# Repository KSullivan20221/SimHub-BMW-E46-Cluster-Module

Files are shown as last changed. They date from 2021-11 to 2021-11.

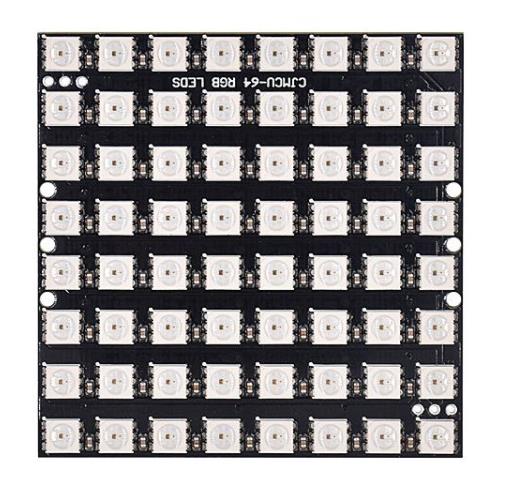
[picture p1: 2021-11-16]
Arduino Code/main-simhub-code/GroupPictures/WS2812B Matrix.jpg

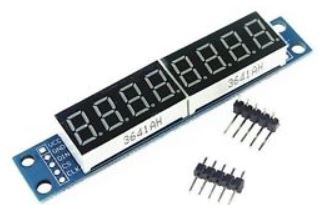
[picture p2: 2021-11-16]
Arduino Code/main-simhub-code/GroupPictures/MAX7221 7 Segments Modules.jpg

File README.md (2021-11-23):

# SimHub-BMW-E46-Cluster-Module
This repo contains all of the circuitry, code, and resources used to create a shield board for an Arduino Mega that could be used to communicate with a BWM E46 instrument cluster from a PC. The main application of this project was in using the cluster in conjunction with SimHub in order to show the values from the supported video games on the cluster's gauges. 

All of the testing I performed was on an E46 cluster with the following ID number and firmware:  
* Cluster Serial Number: 1031098105  
* Cluster Hardware Number: 30  (Can retrieve this by running the on-board 'Test 1' on the cluster, in test 1.5)  
* Cluster Software Number: 360 (Can retrieve this by running the on-board 'Test 1' on the cluster, in test 1.5)  

See the following link for how to retreive this data: https://www.e46fanatics.com/threads/just-found-us-version-of-hidden-menu.239619/

## Credits

There is no way I could have accomplished this project without many of the resources available to me:
* I never would have got off the ground if it weren't for this pinout diagram for the cluster: https://www.bmwgm5.com/E46_IKE_Connections.htm
* I borrowed several functions / hardware connections from _Neuros-Projekte_, as well as most all of the KBUS communication methods: https://neuros-projekte.de/simulator/bmw-e46-arduino-simhub/
* Most all of the CAN communication was from the extensive research done by the users on this bimmerforums forum: https://www.bimmerforums.com/forum/showthread.php?1887229-E46-Can-bus-project
* amstudio on YouTube for introducing me to using SimHub, and providing a solid foundation to design my custom protocol on top of: https://www.youtube.com/watch?v=L59NL9EuEdM&ab_channel=amstudio

# Hardware Design
The circuit designed for this project was designed as a shield for an Arduino Mega microcontroller board. The purpose of this circuit was to take the signals from the Arduino Mega and use them to control the lights, gauges, and serial busses in the cluster. With this design, a user can supply 12V to the DC barrel jack input of the Arduino Mega in order to power the cluster, and then connect a USB-B cable from the computer running the video games to the Arduino to pass data between the computer and the Arduino. 

## Signals required to operate the cluster
In order to determine what signals I needed to drive the cluster, I searched for "E46 cluster pinout" and soon arrived at the following website which provided the pinout for the two connectors on the cluster:
https://www.bmwgm5.com/E46_IKE_Connections.htm

With this, and the help of the people on the following forum, I was able to come up with the following table outlining what signals were required at each pin of the cluster:

BMW CAN Bus Forum: https://www.bimmerforums.com/forum/showthread.php?1887229-E46-Can-bus-project

### X11175 Connector Pin Function / Signal Levels

| Pin Number | Pin Function 	| Detailed Description | Notes 	|
| --- | --- 	| --- | --- 																			 																				|
| 1 | Ground 	| | 																			 																				|
| 2 | Battery Charge Indicator 	| Provides a voltage up to 12 V indicating the batteries voltage level | 																			 																				|
| 3 | Engine Start Signal Feedback 	| Not certain, but seems like 12V into this pin indicates the engine has started | 																			 																				|
| 4 | 12V Power input 	| Always gets 12V from the battery | 																			 																				|
| 5 | 12V On / Start 	| Receives 12V when car is fully on (key turned to second position) | 																			 																				|
| 6 | 12V Accessory / On / Start 	| Receives 12V when car is in accessory mode or when fully on | 																			 																				|
| 7 | Cluster backlight 	| On certain cluster models (not this one), setting to 12V turns backight on | 																			 																				|
| 8 | Speedometer Signal Output 	| Unknown what this does, the cluster I used did not have anything wired here | 																			 																				|
| 9 | CAN-H Signal 	| The CAN High side of the differential pair | 																			 																				|
| 10 | CAN-L Signal 	| The CAN Low side of the differential pair | 																			 																				|
| 11 | Fuel Tank 1 + 	| Pin that fuel tank 1 level sensor positive signal is connected to | 70 Ohms to ground = empty, 395 Ohms to ground = full 													 														|
| 12 | Fuel Tank 1 - 	| Return connection for fuel tank 1 level sensor (sits at ground potential) | Connecting this to ground does not cause issues for this circuit 											 											 	|
| 13 | Oil Pressure Switch 	| Connects to oil pressure sensor | Pulling down to ground = oil pressure issue, leaving unconnected = no issue 										 										|
| 14 | K-Bus Signal 	| K-Bus Communication signal | The K-Bus can be controlled by one of the Arduino's serial peripherals after being level-shifted so that it ranges from 0-12V instead of the Arduino's 0-5V 	|
| 15 | Fuel Tank 2 + 	| Pin that fuel tank 2 level sensor positive signal is connected to | 70 Ohms to ground = empty, 310 Ohms to ground = full 													 														|
| 16 | Fuel Tank 2 - 	| Return connection for fuel tank 2 level senor (sits at ground potential) | Connecting this to ground does not cause issues for this circuit 											 												|
| 17 | Oil Level Sensor 	| Signal that measures how full the engine oil is | Connecting this pin to ground indicates an issue with the oil level, leaving unconnected = no issue 							 							|
| 18 | Service Interval Indicator Reset 	| Not certain what purpose this serves | 																			 																				|
| 19 | Rear-Left Wheel Speed Sensor 	| Signal that connects to wheel speed sensor that drives the speedometer | This is driven by a 12V fixed 50% duty cycle variable frequency square-wave (about 31 Hz = 10 MPH, 1646 Hz = 155 MPH) 				 					|
| 20 | Brake Fluid Level Sensor 	| Signal that connects to brake fluid sensor | Connecting this to ground indicates there is no issue with the brake fluid, leaving this unconnected indicates there is an issue 			 				|
| 21 | Airbag Warning LED 	| Indicates the passenger airbag is ready to engage | Connecting this to ground indicates the airbag is ready to engage, and will illuminate the light on the dashboard  					 						|
| 22 | ABS Warning Light 	| Inicates that ABS is disabled | Connecting to ground indicates that ABS is active, and the thus the LED on the cluster will turn off, and vice versa 					 						|
| 23 | Parking brake switch 	| Indicates that the E-Brake is engaged | Connecting to ground indicates that the parking brake is not engaged, and will cause the 'BRAKE' light to turn off 					 						|
| 24 | Brake wear sensor 	| Indicates when the brakes are worn | Connecting to ground indicates that the brakes are not worn, and the cluster light will turn off, and vice versa 						 						|
| 25 | Diag Signal TX 	| Unsure the function of this signal | 																			 																				|
| 26 | Coolant Level Sensor 	| Indicates if the coolant level is too low | Connecting this to ground indicates that the coolant level is sufficient, and will turn the cluster light off, and vice versa 				 					|

### X11176 Connector Pin Function / Signal Levels

| Pin Number | Pin Function 			| Detailed Description | Notes |
| --- | --- 		 		| --- | --- 																			 											|
| 1 | AT+ Outside Temperature					| Reads data from sensor on the outside temperature			| 3.07kOhm to ground = 95 degrees farenheit, 4.7kOhm to ground = 77 degrees farenheit, 7.33kOhm to ground = 59 degrees farenheit	|
| 2	 	 | AT- Outside Temperature					| Return connection for the outside temperature sensor		| Connecting this to ground does not cause issues for this circuit 												 				|
| 3 	 | Not connected							| N/A											 			|																				 												|
| 4 	 | Washer Fluid Level						| Indicates if the washer fluid level is too low			| Connecting to ground indicates that the washer fluid is filled, and clear the light on the instrument cluster, and vice versa		|
| 5 	 | Cruise Control Active	 		| Signal indicates if cruise control is acitve or not		| Connecting to ground indicates that cruise control is active												 					|
| 6	 	 | Signal Airbag Warning, rollover sensor | Indicates rollover in convertible version of car			| Not sure the polarity of this light as it was not active on this version of the cluster									 	|
| 7	 	 | Reverse									| Only in manual transmission version of car				| Not sure the polarity of this light as it was not active on this version of the cluster									 	|
| 8 	 | Not connected							| N/A											 			|																				 												|
| 9 	 | Not connected							| N/A											 			|																				 												|
| 10 	 | Not connected							| N/A											 			|																				 												|
| 11 	 | Not connected							| N/A											 			|																				 												|
| 12	 | Drivers seat belt						| Light to indicate if the driver's seat belt is engaged	| Connecting to ground indicates that the driver's seat belt is engaged, and vice verse									 		|
| 13	 | BC Button on turn signal stalk			| 											 				| Connecting to ground indicates that the BC button is pressed												 					|
| 14 	 | Signal Gong								| ?											 				| Unsure, but felt like this might engage the beeper on certain models											 				|
| 15 	 | Not connected							| N/A											 			|																				 												|
| 16 	 | Not connected							| N/A											 			|																				 												|
| 17 	 | Not connected							| N/A											 			|																			 													|
| 18 	 | Not connected							| N/A											 			|																				 												|

## Sub-Circuits used in cluster module

### Basic Pull-Down Network

<p align="center">
  
</p>

This circuit in essence acts like a switch: When the Arduino applies 5V to the input of the circuit, the MOSFET (the DMN67D8L-7 part) turn on, and pulls the cluster pin to ground. The current that flows in this case can be up to 30mA, so the part was selected so that it could handle at least this (the selected part can handle up to roughly 200 mA). If the Arduino applies 0V to the input of the circuit, the MOSFET turns off and the cluster pin is pulled back up to 12V. 

This circuit is used to control the following pins:  
X11175 Connector: 13, 17, 19, 20, 21, 22, 23, 24, 26  
X11176 Connector: 4, 5, 6, 7, 12, 13

## 5V to 12V Level Shifter

<p align="center">
  
</p>

This circuit acts very similar to the basic pull-down network: If the Arduino applies 5V on the input of the circuit, Q6 will turn on (connect the cluster pin to 12V), and Q4 will turn off. If the Arduino applies 0V on the input of the circuit, Q6 will turn off, and Q4 will turn on (connect the cluster pin to ground). The 10 Ohm resistor was added to limit the current going into the pin the circuit is connected to. 

This circuit is used to control the following pins:
X11175 Connector: 2, 7
X11176 Connector: 14

## KBUS Level Shifter

<p align="center">
  
</p>

When the Arduino applies 0V to this circuit, Q7 turns off, and pulls the gate of Q9 up to 5V. This turns on Q9, and thus applies 0V to cluster pin 14. When the Arduino applies 5V to this circuit, Q7 turns on, and pulls the gate of Q9 down to ground. This turns off Q9, and thus pulls cluster pin 14 up to 12V. This circuit is used to translate the 5V 'Serial' messages coming from the Arduino to 12V message signals that the cluster expects to see. 

## Ignition and Accessory Mode Circuits

<p align="center">
  
</p>

When the Arduino applies 5V to this circuit, it turns on Q31, which then pulls the gate of Q32 down to ground. Q32 is a PMOS transistor, and thus this turns the FET 'ON' which then applies 12V to the cluster pin. When the Arduino applies 0V to this circuit, it turns Q31 off, which then pulls the gate of Q32 up to 12V. This turns the FET 'OFF' which then pulls the cluster pin down to ground.  

This circuit was used to control the ignition and accessory mode cluster pins (X11175 pins 5 and 6 respectively)

## SPI -> CAN Circuitry

<p align="center">
  
</p>

This circuit is a direct copy of the circuit used on the MCP2515 SPI to CAN development boards, such as this one:

<p align="center">
  
</p>

## Fuel Level Circuit

This circuit is known more commonly as a 'shunt-regulator' (similar to the popular TL431 part you can find available online). This circuit makes more sense when you consider what the circuit on the input of the cluster looks like for X11175 Pins 11 and 15 (Tank1+ and Tank2+ respectively):



In this more simplified circuit, I represent the digital potentiometer as a normal potentiometer, and show what the input of the cluster looks like for the Tank+ pins. The idea is that as we change the value of the potentiometer, the gain of the circuit changes and causes the voltage at the Tank+ pin to change accordingly.   

For example:  
If the potentiometer is set to 0 ohms, the tank+ pin will be set to roughly 0.65V. To the cluster, this would look just the same as connecting a 50 Ohm resistor from the pin to ground. In the case that the potentiometer is set to 5kOhms, the voltage at the take+ pin will be set to roughly 2.7 Volts, which looks just the same as if a 397 Ohms resistor was connected from the pin to ground.   

In this sense, the circuit acts as a variable resistor that we can set from the Arduino ranging between about 50 Ohms and 397 Ohms, which covers the normal operating range for this pin of a resistance value between 70 Ohms and 395 Ohms (see table above for tank+ pins). In theory, the same circuit could have also been used for the ambient temperature sensor, but I chose against this since it did not change system performance at all.

## Other Circuits

There are a few circuits in the design containing connectors, DIP switches, and other such items that I do not cover here as they are more self-explanatory, but if you would like to know about any other part of of the schematic design, please let me know.

# Arduino Code

For this project, I provided two main programs: E46_Cluster_Test, and main-simhub-code. The following section outlines these two programs, as well as the communication protocol that is common to both programs:

## E46_Cluster_Test

This program was created in order to perform basic tests on the cluster. After uploading this code, you can send commands from the serial monitor to the Arduino, and then the Arduino will interact with the cluster in order to carry out the desired function. You must send every command with the following syntax:

<p align="center">
  
</p>

In addition, make sure the Arduino Serial monitor is setup as shown below (most importantly, have the baud rate set to 9600, and the line ending set to 'Newline'):



See the section _Valid Command / Argument Combos for both programs_ for a list of commands that you can send to the cluster, along with the effect each one has.

## main-simhub-code

This program was created in order to interface with the cluster through the computer software _SimHub_, which allows you to send data from racing games to an Arduino. This program receieves data from SimHub, and using the same methods as the _E46_Cluster_Test_ program, sets the cluster up to reflect the sent data. You have to upload this program to the Arduino before attempting to use the SimHub application, or else it will hijack the serial port and not let you program the Arduino until you close the application.   

In order to make this application work with the hardware, you need to do the following:

1. Upload the main-simhub-code sketch to your Arduino
2. Open SimHub, and Navigate to the following menu: Arduino -> My Hardware
3. Confirm that there is a device connected in this menu
4. Under the _Custom Protocol_ for this device, paste in the contents of the _JavaScript_Protocol.txt_ file, and be sure to check the _Use javascript_ box
5. Press OK at the bottom of the window

At this point, you should be able to launch games from the SimHub dashboard (ensure that you configure each game according to SimHub's instructions).

## Valid Command / Argument Combos for both programs

The following is a list of valid commands and arguments that you can send to the instrument cluster from both applications. You can send these commands directly through the serial monitor for the E46_Cluster_Test program, or through a Custom Protocol in SimHub:

| Command | Valid Arguments | Description 				|
| --- | --- | --- 				|
| speed | Integer between 1 and 163 | Sets the speedometer to the desired value in MPH 				|
| rpm | Integer between 0 and 7000 | Sets the tachometer to the desired value  in RPM 				|
| temp | Integer between 65 and 405 | Sets the oil temperature gauge to the desired value in degrees celcius 				|
| ignition | Either 1 or 0 | Turns the ignition state to on / off 				|
| accessory | Either 1 or 0 | Turns the accessory state to on / off 				|
| fuel | Integer between 1 and 100 | Sets the fuel gauge to the desired value (have to cycle 12V power to cluster to change immediately) |
| engineStateFeedback | Either 1 or 0 | No noticeable effect 				|
| signalGong | Either 1 or 0 | No noticeable effect 				|
| bc_button | Either 1 or 0 | No noticeable effect 				|
| seatBelt | Either 1 or 0 | No noticeable effect |
| coolantLevelSensor  | Either 1 or 0 | '0' causes the coolant light to come on, '1' turns it off (have to cycle ignition to change state)  |
| brakeWearSensor | Either 1 or 0 | '0' causes the brake pad wear light to come on, '1' turns it off 				|
| parkingBrakeState | Either 1 or 0 | '0' turns BRAKE light on, '1' turns it off 				|
| ABS_Warning | Either 1 or 0 | '0' turns ABS light on, '1' turns it off 				|
| airbagLight | Either 1 or 0 | '0' turns airbag light off, '1' turns it on 				|
| brakeFluidSensor | Either 1 or 0 | No noticeable effect 				|
| oilSensor | Either 1 or 0 | No noticeable effect 				|
| oilPressureSwitch | Either 1 or 0 | No noticeable effect 				|
| clusterBacklight | Either 1 or 0 | No noticeable effect 				|
| washerFluidLight | Either 1 or 0 | '1' turns the light off, '0' turns it on (have to cycle ignition to change 				|
| cruiseLight | Either 1 or 0 | 				|
| rolloverSensor | Either 1 or 0 | 				|
| reverse | Either 1 or 0 | 				|
| eLight | Either 1 or 0 | '1' turns the _Service Engine Soon_ light on, '0' turns off 				|
| emlLight | Either 1 or 0 | '1' turns the _EML_ light on, '0' turns off 				|
| gasCapLight | Either 1 or 0 | '1' turns the _CHECK GAS CAP_ light on, '0' turns off 				|
| heatLight | Either 1 or 0 | '1' turns the over temperature light on, '0' turns off 				|
| oilLight | Either 1 or 0 | '1' turns the low oil pressure warning light on, '0' turns it off 				|
| chgLight | Either 1 or 0 | '1' turns the battery charge light on, '0' turns it off 				|
| highBeam | Either 1 or 0 | '1' turns the highbeam indicator on, '0' turns it off 				|
| fogRear | Either 1 or 0 | '1' turns the rear fog-light indicator on, '0' turns it off 				|
| fogFront | Either 1 or 0 | '1' turns the front fog-light indicator on, '0' turns it off 				|
| leftBlink | Either 1 or 0 | '1' turns the left blinker on, '0' turns it off 				|
| rightBlink | Either 1 or 0 | '1' turns the right blinker on, '0' turns it off 				|
| backRightLight | Either 1 or 0 | '1' turns the light on, '0' turns it off 				|
| backLeftLight | Either 1 or 0 | '1' turns the light on, '0' turns it off 				|
| frontRightLight | Either 1 or 0 | '1' turns the light on, '0' turns it off 				|
| frontLeftLight | Either 1 or 0 | '1' turns the light on, '0' turns it off 				|
| carLight | Either 1 or 0 | '1' turns the light on, '0' turns it off 				|

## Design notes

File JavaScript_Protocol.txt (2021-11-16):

// Global Variables
let send_str = ""

// Conditionally define data sent depending on what game we are playing
let currentGame = $prop('DataCorePlugin.CurrentGame')

if(currentGame=='ETS2') {
	// Fuel Data
	let rounded_fuel = Math.round($prop('FuelPercent'), 2);
	send_str = send_str.concat('fuel:' + rounded_fuel + '\n');
	
	// Speed Data
	let rounded_speed = Math.round($prop('SpeedMph'), 2);
	send_str = send_str.concat('speed:' + rounded_speed + '\n');

	// RPM Data
	let rounded_RPM = Math.round($prop('Rpms'), 2);
	send_str = send_str.concat('rpm:' + rounded_RPM + '\n');

	// Oil temperature
	let rounded_temp = Math.round($prop('OilTemperature'), 2);
	send_str = send_str.concat('temp:' + rounded_temp + '\n');
	
	// Truck Status
	let engine_state = $prop('GameRawData.TruckValues.CurrentValues.DamageValues.Engine');
	let wheel_state = $prop('GameRawData.TruckValues.CurrentValues.DamageValues.WheelsAvg');
	let chassis_state = $prop('GameRawData.TruckValues.CurrentValues.DamageValues.Chassis');
	let transmission_state = $prop('GameRawData.TruckValues.CurrentValues.DamageValues.Transmission');
	let cabin_state = $prop('GameRawData.TruckValues.CurrentValues.DamageValues.Cabin');
	
	// Blinkers
	let left_blinker_state = $prop('GameRawData.TruckValues.CurrentValues.LightsValues.BlinkerLeftActive');
	if (left_blinker_state == 1) {
		send_str = send_str.concat('leftBlink:1\n');
	}
	else {
		send_str = send_str.concat('leftBlink:0\n');
	}
	
	let right_blinker_state = $prop('GameRawData.TruckValues.CurrentValues.LightsValues.BlinkerRightActive');
	if (right_blinker_state == 1) {
		send_str = send_str.concat('rightBlink:1\n');
	}
	else {
		send_str = send_str.concat('rightBlink:0\n');
	}	
	
	// Car ignition
	let ignition_state = $prop('EngineIgnitionOn');
	send_str = send_str.concat('ignition:' + ignition_state + '\n');

	// Car Accessory Mode
	if(ignition_state == 1) {
		send_str = send_str.concat('accessory:1\n');
	}
	else {
		send_str = send_str.concat('accessory:0\n');
	}
	
	// High-Beam state
	let highbeam_state = $prop('GameRawData.TruckValues.CurrentValues.LightsValues.BeamHigh');
	if(highbeam_state == 1) {
		send_str = send_str.concat('highBeam:1\n');
	}
	else {
		send_str = send_str.concat('highBeam:0\n');
	}

}
else if(currentGame == 'PCars') {
	// Fuel Data
	let rounded_fuel = Math.round($prop('FuelPercent'), 2);
	send_str = send_str.concat('fuel:' + rounded_fuel + '\n');
	
	// Speed Data
	let rounded_speed = Math.round($prop('SpeedMph'), 2);
	send_str = send_str.concat('speed:' + rounded_speed + '\n');

	// RPM Data
	let rounded_RPM = Math.round($prop('Rpms'), 2);
	send_str = send_str.concat('rpm:' + rounded_RPM + '\n');

	// Oil temperature
	let rounded_temp = Math.round($prop('OilTemperature'), 2);
	send_str = send_str.concat('temp:' + rounded_temp + '\n');
	
	// Ignition and accessory modes
	send_str = send_str.concat('ignition:1\n');
	send_str = send_str.concat('accessory:1\n');

}
else {
	// This is the general area, where we can guess at what commands we think might be general enough for the rest 
	// of the games that may be played
	
	// Speed Data
	let rounded_speed = Math.round($prop('SpeedMph'), 2);
	send_str = send_str.concat('speed:' + rounded_speed + '\n');
	
	// RPM Data
	let rounded_RPM = Math.round($prop('Rpms'), 2);
	send_str = send_str.concat('rpm:' + rounded_RPM + '\n');
	
	// Oil temperature
	let rounded_temp = Math.round($prop('OilTemperature'), 2);
	send_str = send_str.concat('temp:' + rounded_temp + '\n');
	
	// Fuel data (100% default)
	send_str = send_str.concat('fuel:100\n');
	
	// Ignition and accessory modes
	send_str = send_str.concat('ignition:1\n');
	send_str = send_str.concat('accessory:1\n');
}

send_str = send_str.concat('end:');

// Send Commands to the Arduino
return send_str
//return $prop('GameRawData.TruckValues.CurrentValues.LightsValues.BlinkerRightActive');

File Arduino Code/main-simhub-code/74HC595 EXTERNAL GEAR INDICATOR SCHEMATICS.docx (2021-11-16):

EXTERNAL GEAR INDICATOR SCHEMATICS

7 segment digit - common cathode (ground in the middle)



White - A segment - Q7 PIN on 74HC595
Brown -B segment - Q6 PIN
Orange - C segment - Q5 PIN
Purple - D segment - Q4 PIN
Blue - E segment - Q3 PIN
Green - F segment - Q2 PIN
Yellow - G segment - Q1 PIN

If u want to use DP/H (DOT), connect it to the second left top pin Q0, but its not used in the sketch right now.

Data PINs:
DS (serial data input) - D2 on Arduino
ST_CP (Storage register clock pin "Latch pin") - D3
SH_CP (Shift register clock pin) - D4

Resistor R220 Ohm. (used just one on cathodes, but its better to use 7 resistors, one for every led diode - between Qpins and display)

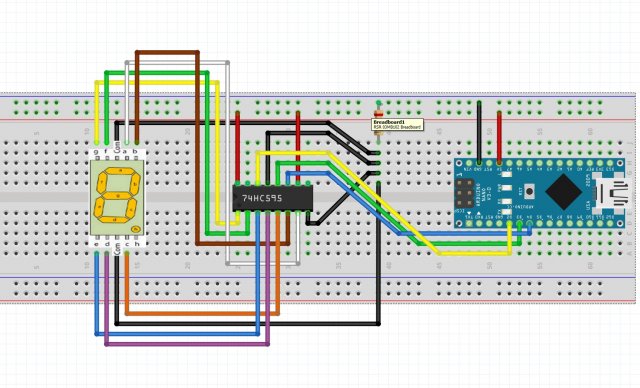
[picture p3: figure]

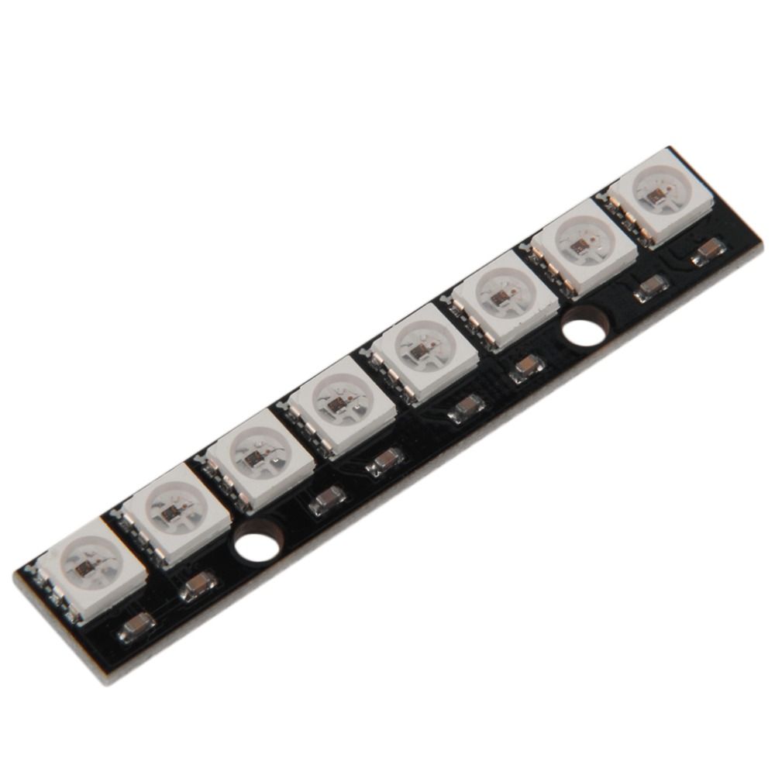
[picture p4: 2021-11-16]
Arduino Code/main-simhub-code/GroupPictures/WS2812B RGB Leds.jpg

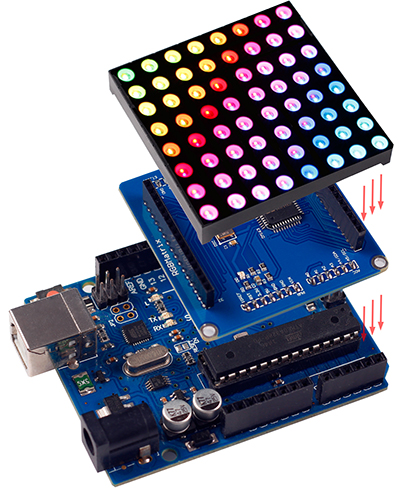
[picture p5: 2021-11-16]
Arduino Code/main-simhub-code/GroupPictures/DM163 RGB MATRIX.jpg

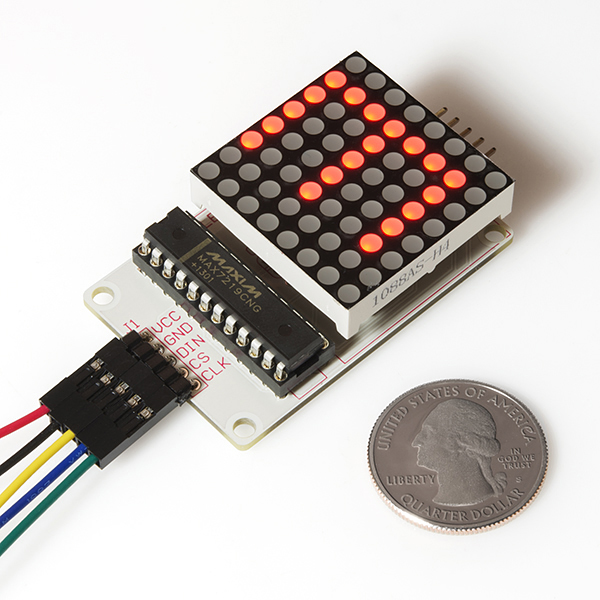
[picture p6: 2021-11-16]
Arduino Code/main-simhub-code/GroupPictures/MAX7221 Led Matrix.jpg

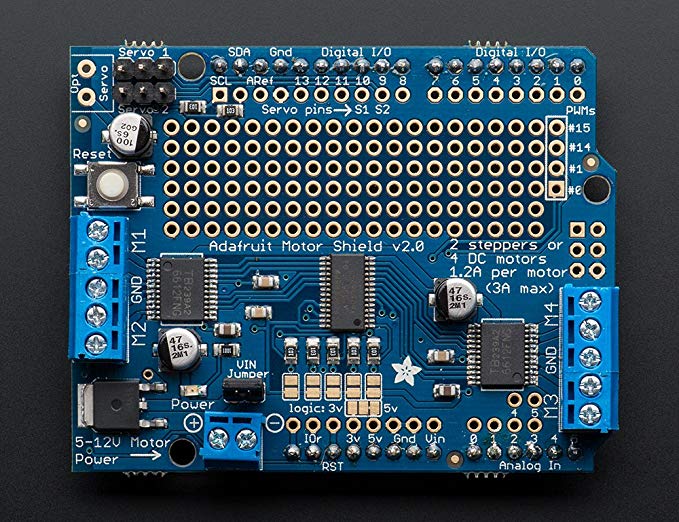
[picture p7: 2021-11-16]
Arduino Code/main-simhub-code/GroupPictures/SHAKEIT ADAFRUIT MOTORSHIELD V2.jpg

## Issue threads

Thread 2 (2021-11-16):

DSC / ABS Issue

KSullivan20221, 2021-11-16:
Unsure how many cluster types this would affect, but the DSC and brake light are stuck on on my system. From my research, it seems that this is due to the fact that the Arduino is not currently sending the following CAN ID commands:
* 0x1F0
* 0x610

From the following forum, it outlines what needs to be put into these messages:
https://www.bimmerforums.com/forum/showthread.php?1887229-E46-Can-bus-project

The issue is that for ARBID 0x610, I have no knowledge of the VIN number associated with my cluster (it was obtained from a junkyard, and did not take note of this). Therefore, without this information, I don't believe you can clear the DSC / brake light always being on.

Ringeltier, 2025-04-18:
Hmm it comes to which ABS module the IKE is coded, if its coded to DSC you will need the VIN if you change it to ASC, you do not need to worry about the VIN.
But for the VIN you could also simply connect BMW-Scanner to I-Bus on Pin 25 - Black and read your VIN from there.
To change from DSC to ASC you would need to have a separate K/D-Can Coder with NCExpert, then you can can simply manipulate and overwrite the configuration and reflash it.

When changed to ASC, all you need for the ESP light is the following. This also CAN-ID allows control of the speed signal over CAN (this needs also to be changed via BMW-Scanner or NCExpert)

Note I set the asc light with either sending the can messing or not. Normally you could control it with byte 1 asc status light should be 0x80. Unfortunately my IKE is exactly at a bad production year. It already supports CAN but not fully. It expects 0x153 to fully work but sending any status bit does not change anything. Also sending CAN-Speed unfortunately did not worked in my case, needed to use frequency signal pin for rear wheel speed sensor. Any IKE above year 2000 should fully support any CAN-ID
```
void updateASCLight(MCP2515 &can, float speedKph, bool asc_state) {
  if (asc_state) {
    uint16_t speed_val = (uint16_t)(speedKph * 256 / 8);
    sendCanMessage(can, 0x153, 0x00, speed_val & 0xFF, (speed_val >> 8) & 0xFF, 0x00, 0x00, 0x00, 0x00, 0x00);
  }
}
```

For ABS I simply use the pin for ABS and set it to high or low

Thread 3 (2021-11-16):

MPG Issue

KSullivan20221, 2021-11-16:
I believe that this issue is related to the DSC / ABS issue. The problem is that I was never able to successfully set the MPG gauge, as it seems to be the most challenging to control. If anyone has any information on this, it would help a lot

Ringeltier, 2025-04-18:
It is challenging. I got it to work. Key Points for working MPG are the following.
RPM needs to be set and not 0
Speed needle needs to be set
and most crucial the MPG value is an increasing value which overflows to 0 what the ike expects. The code is way not perfect and can be tweaked in many ways, but atleast its working
```
void updateWarningIndicators(MCP2515 &can_bus, int engine_light_state, int cruise_light_state, int EML_state,
                             int gas_cap_light_state, int heat_light_state, int oil_light_state,
                             int charge_light_state, float throttle, int temp_val, float rpm_val, float speed_val) {
  uint8_t status1_byte = 0x00;
  if (engine_light_state) status1_byte |= (1 << 1);
  if (cruise_light_state) status1_byte |= (1 << 3);
  if (EML_state) status1_byte |= (1 << 4);
  if (gas_cap_light_state) status1_byte |= (1 << 6);

  // Base fuel consumption from speed & RPM
  int fuel_consumption =
    map(throttle, 0, 100, 0, 220); // Throttle dominates

  // RPM and speed only lightly contribute
  fuel_consumption += map(rpm_val, 600, 6000, 1, 30);
  fuel_consumption += map(speed_val, 0, 240, 1, 25);

  // Extra fuel usage for aggressive driving
  if (rpm_val > 5000 || speed_val > 180) fuel_consumption += 50;

  // This part is crucial
  fuel_consumption_total += fuel_consumption;

  uint8_t fuel_LSB = fuel_consumption_total & 0xFF;
  uint8_t fuel_MSB = (fuel_consumption_total >> 8) & 0xFF;

  if (temp_val >= (MAX_TEMP-10)) heat_light_state = 1;

  int status_byte2 = (heat_light_state << 3) | (oil_light_state << 1);

  sendCanMessage(can_bus, 0x545, status1_byte, fuel_LSB, fuel_MSB, status_byte2, 0x00, charge_light_state, 0x00, 0x00);
}
```

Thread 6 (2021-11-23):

Seat belt issue

KSullivan20221, 2021-11-23:
Although I found resources online to suggest that you could control this pin from pin12 of the connector, I found this not to be true for the cluster I had (the light constantly remained illuminated regardless of how I tied this pin).

Ringeltier, 2025-04-18:
You can change the behaviour of the seat belt to be not checked and automatically turn. This is possible with for e.g. BMW Scanner. Simply connect 12V, Ground and I-Bus on the BMW-Scanner coding module and on the Cluster connect ground and Pin 25 - Diag Signal TX.

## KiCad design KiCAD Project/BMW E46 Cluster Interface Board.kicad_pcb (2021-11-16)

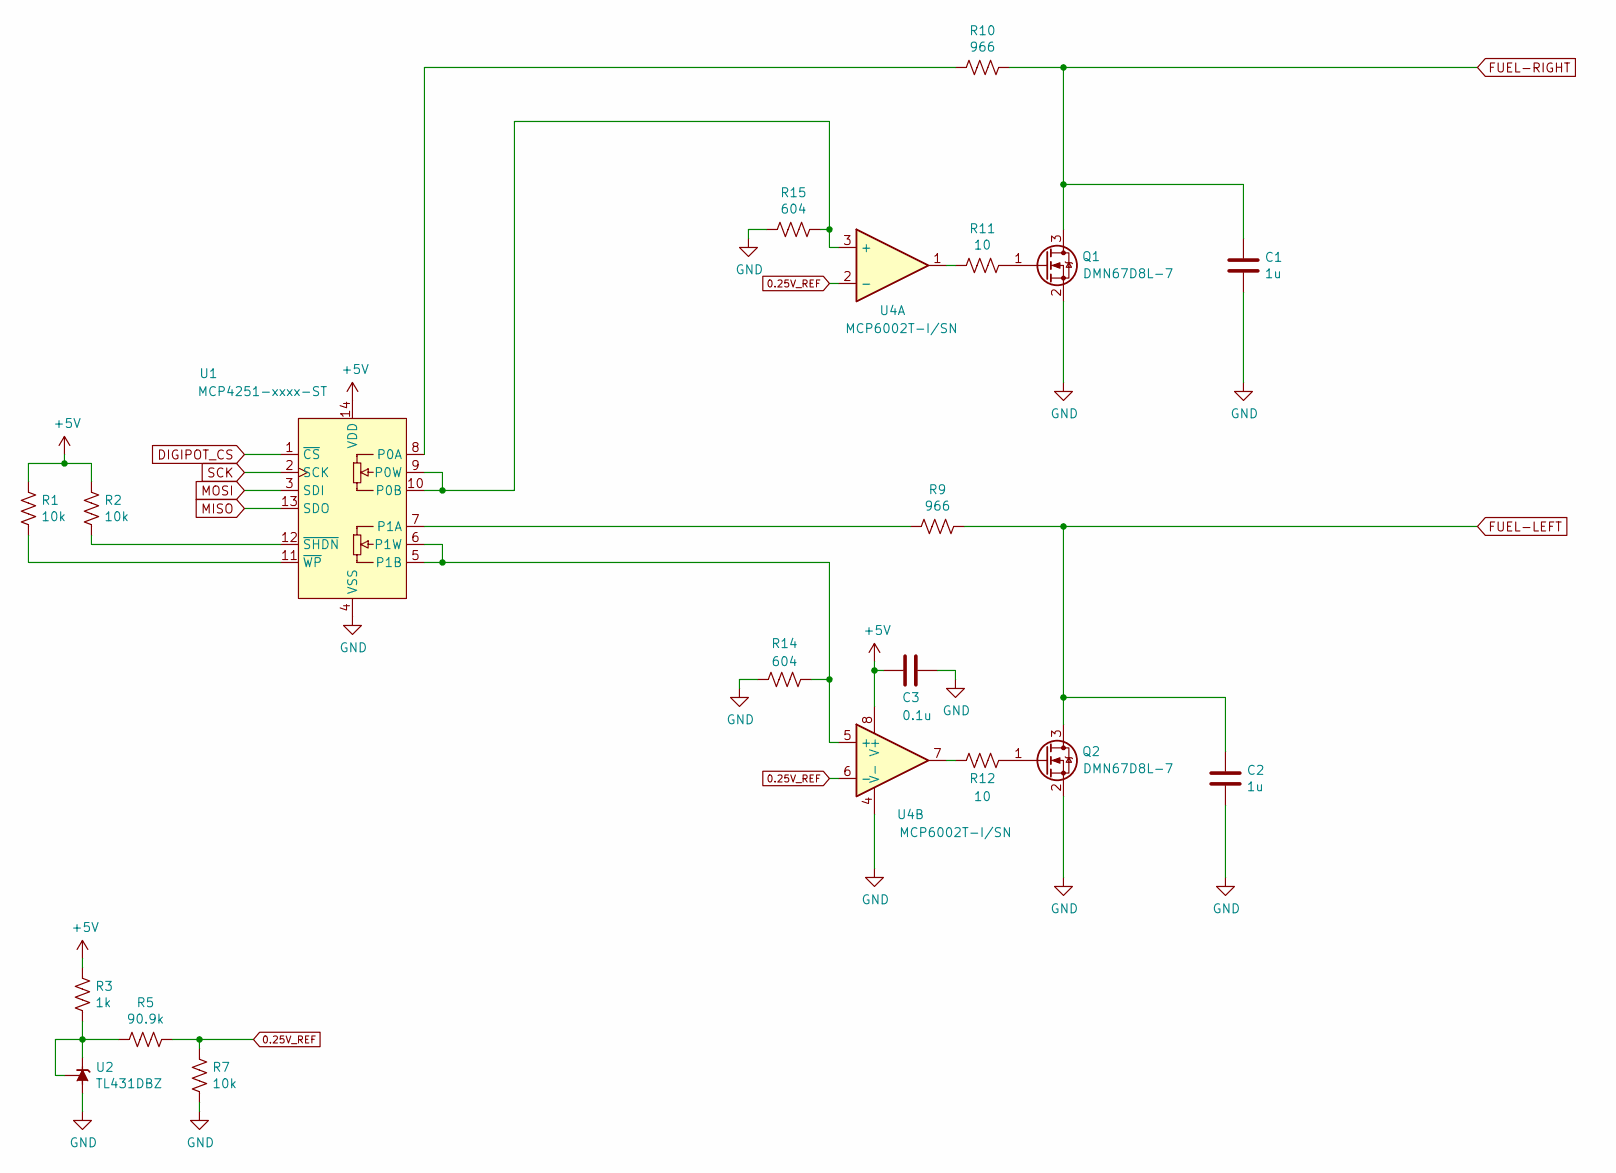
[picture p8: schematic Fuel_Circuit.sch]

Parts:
C1, C2: 1u; C_0805_2012Metric
C3: 0.1u; C_0805_2012Metric
Q1, Q2: DMN67D8L-7; SOT-23
R1, R2, R7: 10k; R_0603_1608Metric
R3: 1k; R_0603_1608Metric
R5: 90.9k; R_0603_1608Metric
R9, R10: 966; R_0603_1608Metric
R11, R12: 10; R_0603_1608Metric
R14, R15: 604; R_0603_1608Metric
U1: MCP4251-xxxx-ST; TSSOP-14_4.4x5mm_P0.65mm
U2: TL431DBZ; SOT-23
U4: MCP6002T-I/SN; SOIC-8_3.9x4.9mm_P1.27mm

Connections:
0.25V_REF: R5.1, R7.2, U4.2 (-), U4.6 (-)
+5V: C3.2, R1.2, R2.2, R3.1, U1.14 (VDD), U4.8 (V+); also elsewhere on the board
DIGIPOT_CS: U1.1 (~CS); also elsewhere on the board
FUEL-LEFT: C2.1, Q2.3 (D), R9.1; also elsewhere on the board
FUEL-RIGHT: C1.1, Q1.3 (D), R10.1; also elsewhere on the board
GND: C1.2, C2.2, C3.1, Q1.2 (S), Q2.2 (S), R7.1, R14.2, R15.2, U1.4 (VSS), U2.3 (A), U4.4 (V-); also elsewhere on the board
MISO: U1.13 (SDO); also elsewhere on the board
MOSI: U1.3 (SDI); also elsewhere on the board
unnamed: Q1.1 (G), R11.1
unnamed: Q2.1 (G), R12.1
unnamed: R1.1, U1.11 (~WP)
unnamed: R2.1, U1.12 (~SHDN)
unnamed: R3.2, R5.2, U2.1 (K), U2.2 (REF)
unnamed: R9.2, U1.7 (P1A)
unnamed: R10.2, U1.8 (P0A)
unnamed: R11.2, U4.1
unnamed: R12.2, U4.7
unnamed: R14.1, U1.5 (P1B), U1.6 (P1W), U4.5 (+)
unnamed: R15.1, U1.9 (P0W), U1.10 (P0B), U4.3 (+)
SCK: U1.2 (SCK); also elsewhere on the board

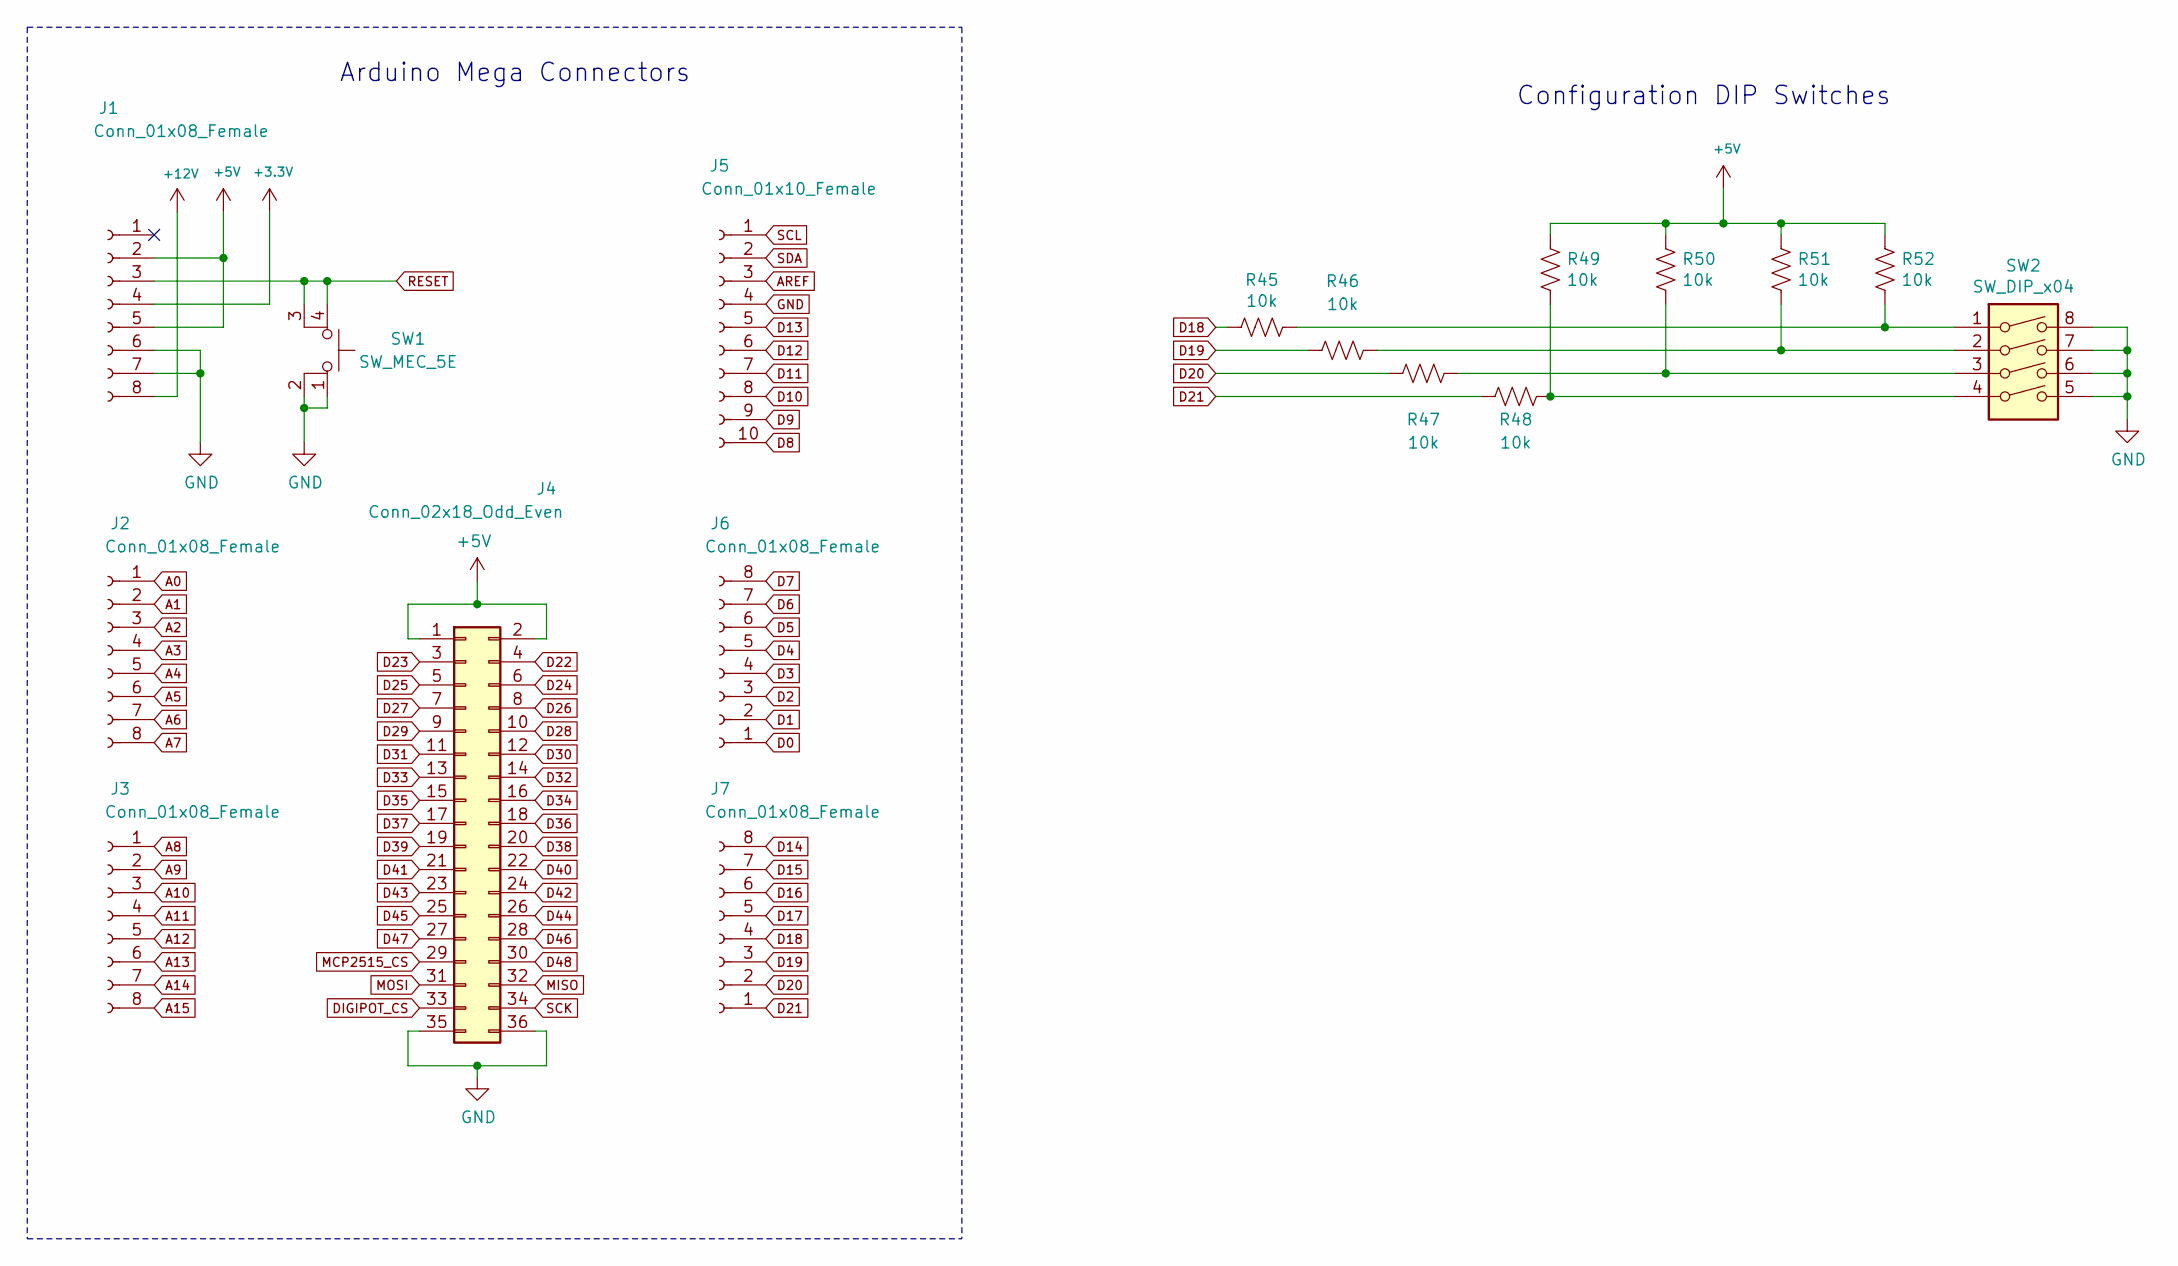
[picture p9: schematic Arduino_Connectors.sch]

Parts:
J1, J2, J3, J6, J7: Conn_01x08_Female; PinSocket_1x08_P2.54mm_Vertical
J4: Conn_02x18_Odd_Even; PinSocket_2x18_P2.54mm_Vertical
J5: Conn_01x10_Female; PinSocket_1x10_P2.54mm_Vertical
R45, R46, R47, R48, R49, R50, R51, R52: 10k; R_0603_1608Metric
SW1: SW_MEC_5E; SW_SPST_Omron_B3FS-101xP
SW2: SW_DIP_x04; SW_DIP_SPSTx04_Slide_9.78x12.34mm_W8.61mm_P2.54mm

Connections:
+3V3: J1.4
+5V: J1.2, J1.5, J4.1, J4.2, R49.1, R50.1, R51.1, R52.1; also elsewhere on the board
+12V: J1.8; also elsewhere on the board
A0: J2.1
A1: J2.2; also elsewhere on the board
A2: J2.3; also elsewhere on the board
A3: J2.4; also elsewhere on the board
A4: J2.5; also elsewhere on the board
A5: J2.6; also elsewhere on the board
A6: J2.7; also elsewhere on the board
A7: J2.8; also elsewhere on the board
A8: J3.1
A9: J3.2
A10: J3.3
A11: J3.4
A12: J3.5
A13: J3.6
A14: J3.7
A15: J3.8
AREF: J5.3
D0: J6.1
D1: J6.2
D2: J6.3; also elsewhere on the board
D3: J6.4; also elsewhere on the board
D4: J6.5; also elsewhere on the board
D5: J6.6; also elsewhere on the board
D6: J6.7; also elsewhere on the board
D7: J6.8; also elsewhere on the board
D8: J5.10; also elsewhere on the board
D9: J5.9; also elsewhere on the board
D10: J5.8; also elsewhere on the board
D11: J5.7; also elsewhere on the board
D12: J5.6; also elsewhere on the board
D13: J5.5; also elsewhere on the board
D14: J7.8; also elsewhere on the board
D15: J7.7; also elsewhere on the board
D16: J7.6; also elsewhere on the board
D17: J7.5
D18: J7.4, R45.2
D19: J7.3, R46.2
D20: J7.2, R47.2
D21: J7.1, R48.2
D22: J4.4
D23: J4.3
D24: J4.6
D25: J4.5
D26: J4.8
D27: J4.7
D28: J4.10
D29: J4.9
D30: J4.12
D31: J4.11
D32: J4.14
D33: J4.13
D34: J4.16
D35: J4.15
D36: J4.18
D37: J4.17
D38: J4.20
D39: J4.19
D40: J4.22
D41: J4.21
D42: J4.24
D43: J4.23
D44: J4.26
D45: J4.25
D46: J4.28
D47: J4.27
D48: J4.30
DIGIPOT_CS: J4.33; also elsewhere on the board
GND: J1.6, J1.7, J4.35, J4.36, J5.4, SW1.1, SW1.2, SW2.5, SW2.6, SW2.7, SW2.8; also elsewhere on the board
MCP2515_CS: J4.29; also elsewhere on the board
MISO: J4.32; also elsewhere on the board
MOSI: J4.31; also elsewhere on the board
unnamed: R45.1, R52.2, SW2.1
unnamed: R46.1, R51.2, SW2.2
unnamed: R47.1, R50.2, SW2.3
unnamed: R48.1, R49.2, SW2.4
RESET: J1.3, SW1.3 (K), SW1.4 (A)
SCK: J4.34; also elsewhere on the board
SCL: J5.1
SDA: J5.2

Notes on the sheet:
Arduino Mega Connectors
Configuration DIP Switches

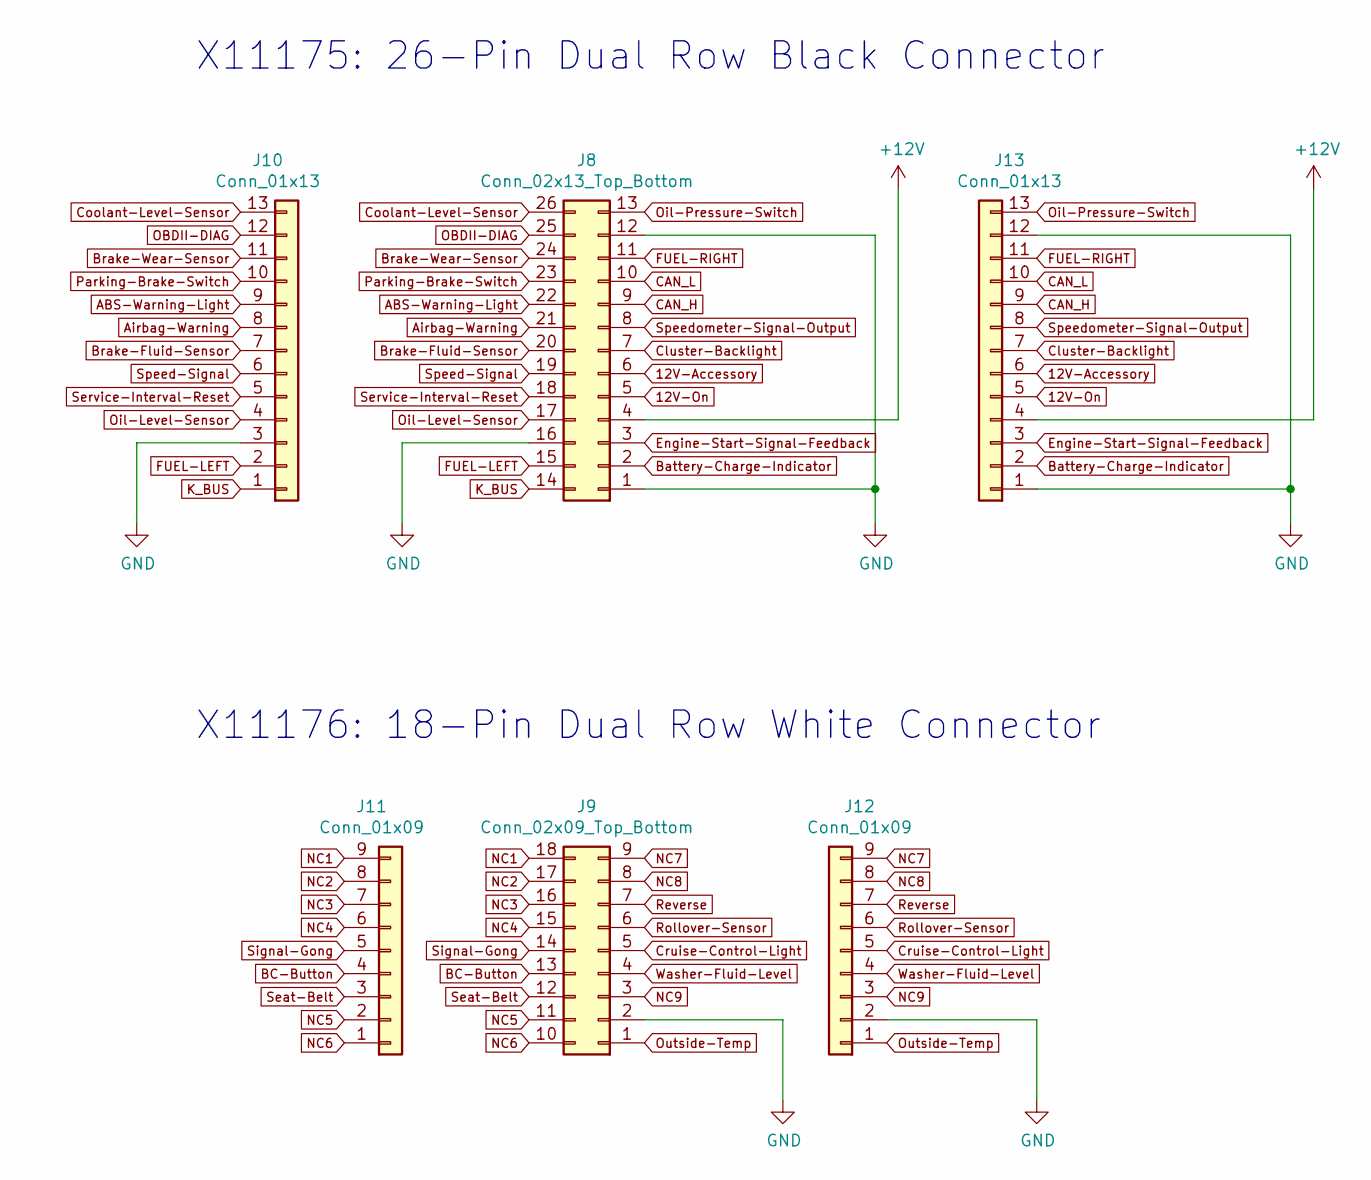
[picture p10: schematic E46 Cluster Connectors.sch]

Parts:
J8: Conn_02x13_Top_Bottom; 3020-26-0300-00
J9: Conn_02x09_Top_Bottom; PinHeader_2x09_P2.00mm_Vertical_SMD_Top_Bottom;98424-G52-18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
J10, J13: Conn_01x13; PinHeader_1x13_P2.54mm_Vertical
J11, J12: Conn_01x09; PinHeader_1x09_P2.54mm_Vertical

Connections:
12V-Accessory: J8.6, J13.6; also elsewhere on the board
12V-On: J8.5, J13.5; also elsewhere on the board
+12V: J8.4, J13.4; also elsewhere on the board
ABS-Warning-Light: J8.22, J10.9; also elsewhere on the board
Airbag-Warning: J8.21, J10.8; also elsewhere on the board
BC-Button: J9.13, J11.4; also elsewhere on the board
Battery-Charge-Indicator: J8.2, J13.2; also elsewhere on the board
Brake-Fluid-Sensor: J8.20, J10.7; also elsewhere on the board
Brake-Wear-Sensor: J8.24, J10.11; also elsewhere on the board
CAN_H: J8.9, J13.9; also elsewhere on the board
CAN_L: J8.10, J13.10; also elsewhere on the board
Cluster-Backlight: J8.7, J13.7; also elsewhere on the board
Coolant-Level-Sensor: J8.26, J10.13; also elsewhere on the board
Cruise-Control-Light: J9.5, J12.5; also elsewhere on the board
Engine-Start-Signal-Feedback: J8.3, J13.3; also elsewhere on the board
FUEL-LEFT: J8.15, J10.2; also elsewhere on the board
FUEL-RIGHT: J8.11, J13.11; also elsewhere on the board
GND: J8.1, J8.12, J8.16, J9.2, J10.3, J12.2, J13.1, J13.12; also elsewhere on the board
K_BUS: J8.14, J10.1; also elsewhere on the board
NC1: J9.18, J11.9
NC2: J9.17, J11.8
NC3: J9.16, J11.7
NC4: J9.15, J11.6
NC5: J9.11, J11.2
NC6: J9.10, J11.1
NC7: J9.9, J12.9
NC8: J9.8, J12.8
NC9: J9.3, J12.3
OBDII-DIAG: J8.25, J10.12
Oil-Level-Sensor: J8.17, J10.4; also elsewhere on the board
Oil-Pressure-Switch: J8.13, J13.13; also elsewhere on the board
Outside-Temp: J9.1, J12.1; also elsewhere on the board
Parking-Brake-Switch: J8.23, J10.10; also elsewhere on the board
Reverse: J9.7, J12.7; also elsewhere on the board
Rollover-Sensor: J9.6, J12.6; also elsewhere on the board
Seat-Belt: J9.12, J11.3; also elsewhere on the board
Service-Interval-Reset: J8.18, J10.5
Signal-Gong: J9.14, J11.5; also elsewhere on the board
Speed-Signal: J8.19, J10.6; also elsewhere on the board
Speedometer-Signal-Output: J8.8, J13.8
Washer-Fluid-Level: J9.4, J12.4; also elsewhere on the board

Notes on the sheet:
X11176: 18-Pin Dual Row White Connector
X11175: 26-Pin Dual Row Black Connector

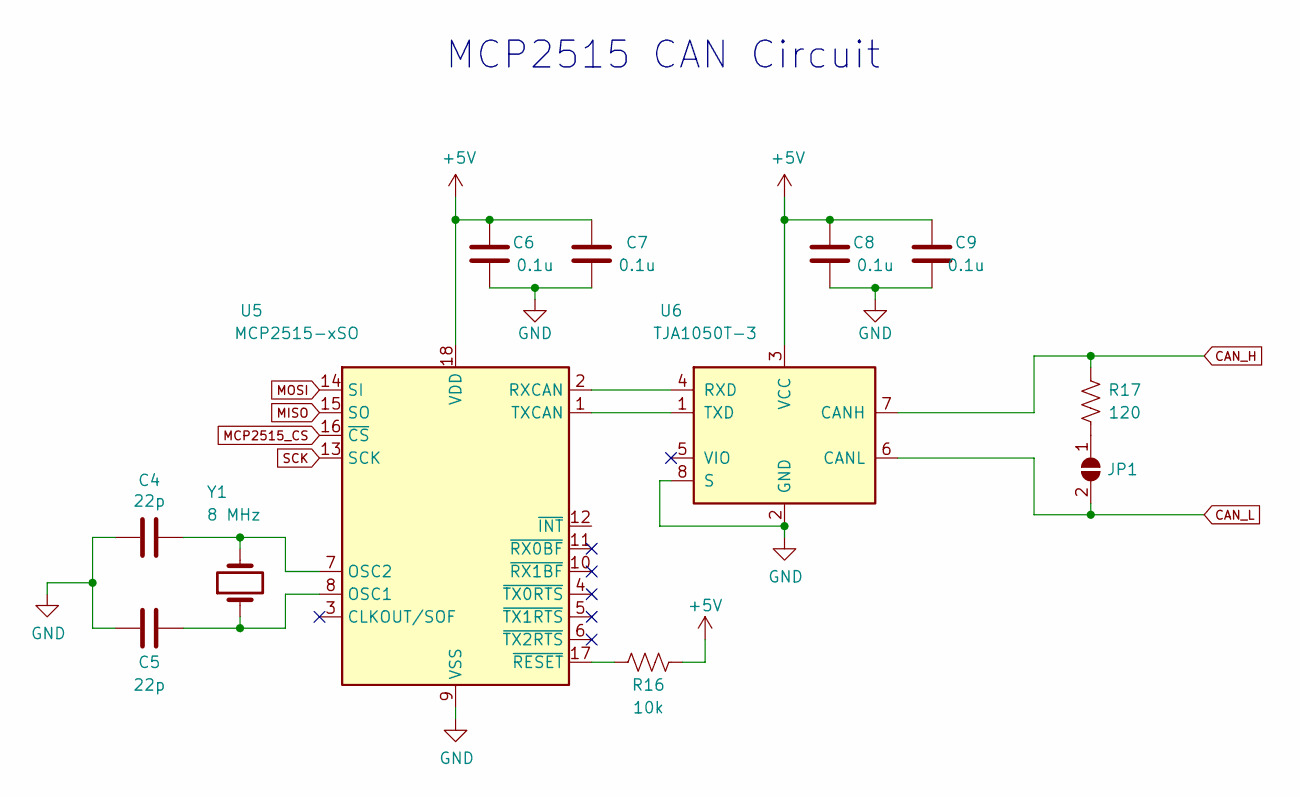
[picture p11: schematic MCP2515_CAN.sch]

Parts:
C4, C5: 22p; C_0603_1608Metric
C6, C7, C8, C9: 0.1u; C_0805_2012Metric
JP1: SolderJumper_2_Open; SolderJumper-2_P1.3mm_Open_Pad1.0x1.5mm
R16: 10k; R_0603_1608Metric
R17: 120; R_0603_1608Metric
U5: MCP2515-xSO; SOIC-18W_7.5x11.6mm_P1.27mm
U6: TJA1050T-3; SOIC-8_3.9x4.9mm_P1.27mm
Y1: 8 MHz; Crystal_SMD_5032-4Pin_5.0x3.2mm

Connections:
+5V: C6.1, C7.1, C8.1, C9.1, R16.1, U5.18 (VDD), U6.3 (VCC); also elsewhere on the board
CAN_H: R17.1, U6.7 (CANH); also elsewhere on the board
CAN_L: JP1.2 (B), U6.6 (CANL); also elsewhere on the board
GND: C4.2, C5.2, C6.2, C7.2, C8.2, C9.2, U5.9 (VSS), U6.2 (GND), U6.8 (S); also elsewhere on the board
MCP2515_CS: U5.16 (~CS); also elsewhere on the board
MISO: U5.15 (SO); also elsewhere on the board
MOSI: U5.14 (SI); also elsewhere on the board
unnamed: C4.1, U5.7 (OSC2), Y1.2
unnamed: C5.1, U5.8 (OSC1), Y1.1
unnamed: JP1.1 (A), R17.2
unnamed: R16.2, U5.17 (~RESET)
unnamed: U5.1 (TXCAN), U6.1 (TXD)
unnamed: U5.2 (RXCAN), U6.4 (RXD)
SCK: U5.13 (SCK); also elsewhere on the board

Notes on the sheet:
MCP2515 CAN Circuit

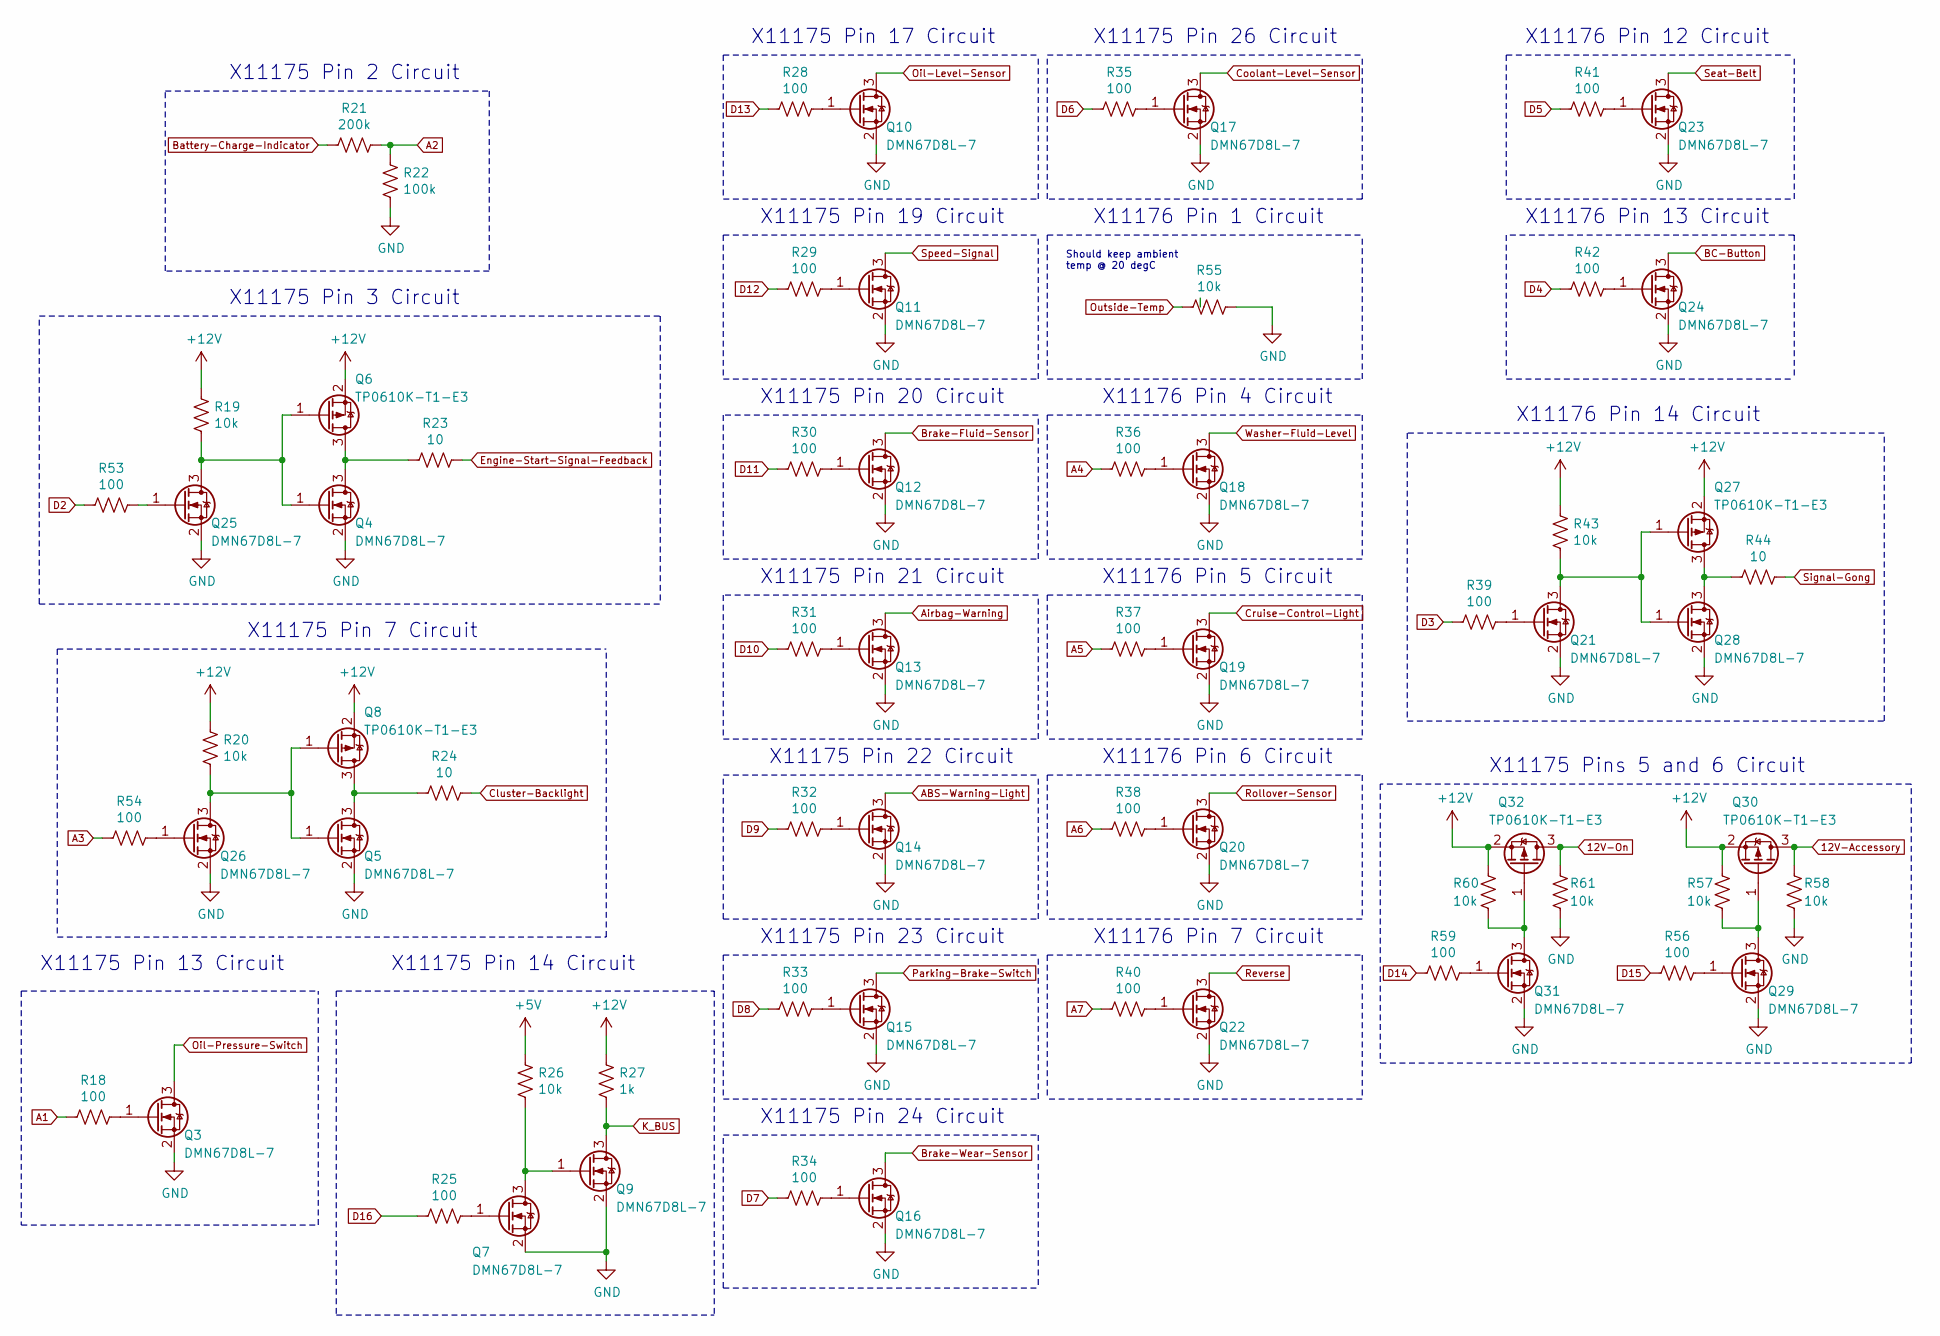
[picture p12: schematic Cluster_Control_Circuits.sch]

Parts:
Q3, Q4, Q5, Q7, Q9, Q10, Q11, Q12, Q13, Q14, Q15, Q16, Q17, Q18, Q19, Q20, Q21, Q22, Q23, Q24, Q25, Q26, Q28, Q29, Q31: DMN67D8L-7; SOT-23
Q6, Q8, Q27, Q30, Q32: TP0610K-T1-E3; SOT-23
R18, R25, R28, R29, R30, R31, R32, R33, R34, R35, R36, R37, R38, R39, R40, R41, R42, R53, R54, R56, R59: 100; R_0603_1608Metric
R19, R20, R26, R43, R55, R57, R58, R60, R61: 10k; R_0603_1608Metric
R21: 200k; R_0603_1608Metric
R22: 100k; R_0603_1608Metric
R23, R24, R44: 10; R_0603_1608Metric
R27: 1k; R_0603_1608Metric

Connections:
12V-Accessory: Q30.3 (D), R58.1; also elsewhere on the board
12V-On: Q32.3 (D), R61.1; also elsewhere on the board
+5V: R26.2; also elsewhere on the board
+12V: Q6.2 (S), Q8.2 (S), Q27.2 (S), Q30.2 (S), Q32.2 (S), R19.1, R20.1, R27.1, R43.1, R57.1, R60.1; also elsewhere on the board
A1: R18.1; also elsewhere on the board
A2: R21.1, R22.1; also elsewhere on the board
A3: R54.2; also elsewhere on the board
A4: R36.2; also elsewhere on the board
A5: R37.2; also elsewhere on the board
A6: R38.2; also elsewhere on the board
A7: R40.2; also elsewhere on the board
ABS-Warning-Light: Q14.3 (D); also elsewhere on the board
Airbag-Warning: Q13.3 (D); also elsewhere on the board
BC-Button: Q24.3 (D); also elsewhere on the board
Battery-Charge-Indicator: R21.2; also elsewhere on the board
Brake-Fluid-Sensor: Q12.3 (D); also elsewhere on the board
Brake-Wear-Sensor: Q16.3 (D); also elsewhere on the board
Cluster-Backlight: R24.1; also elsewhere on the board
Coolant-Level-Sensor: Q17.3 (D); also elsewhere on the board
Cruise-Control-Light: Q19.3 (D); also elsewhere on the board
D2: R53.2; also elsewhere on the board
D3: R39.2; also elsewhere on the board
D4: R42.2; also elsewhere on the board
D5: R41.2; also elsewhere on the board
D6: R35.2; also elsewhere on the board
D7: R34.2; also elsewhere on the board
D8: R33.2; also elsewhere on the board
D9: R32.2; also elsewhere on the board
D10: R31.2; also elsewhere on the board
D11: R30.2; also elsewhere on the board
D12: R29.2; also elsewhere on the board
D13: R28.2; also elsewhere on the board
D14: R59.2; also elsewhere on the board
D15: R56.2; also elsewhere on the board
D16: R25.1; also elsewhere on the board
Engine-Start-Signal-Feedback: R23.1; also elsewhere on the board
GND: Q3.2 (S), Q4.2 (S), Q5.2 (S), Q7.2 (S), Q9.2 (S), Q10.2 (S), Q11.2 (S), Q12.2 (S), Q13.2 (S), Q14.2 (S), Q15.2 (S), Q16.2 (S), Q17.2 (S), Q18.2 (S), Q19.2 (S), Q20.2 (S), Q21.2 (S), Q22.2 (S), Q23.2 (S), Q24.2 (S), Q25.2 (S), Q26.2 (S), Q28.2 (S), Q29.2 (S), Q31.2 (S), R22.2, R55.2, R58.2, R61.2; also elsewhere on the board
K_BUS: Q9.3 (D), R27.2; also elsewhere on the board
unnamed: Q3.1 (G), R18.2
unnamed: Q4.3 (D), Q6.3 (D), R23.2
unnamed: Q5.3 (D), Q8.3 (D), R24.2
unnamed: Q7.1 (G), R25.2
unnamed: Q7.3 (D), Q9.1 (G), R26.1
unnamed: Q10.1 (G), R28.1
unnamed: Q11.1 (G), R29.1
unnamed: Q12.1 (G), R30.1
unnamed: Q13.1 (G), R31.1
unnamed: Q14.1 (G), R32.1
unnamed: Q15.1 (G), R33.1
unnamed: Q16.1 (G), R34.1
unnamed: Q17.1 (G), R35.1
unnamed: Q18.1 (G), R36.1
unnamed: Q19.1 (G), R37.1
unnamed: Q20.1 (G), R38.1
unnamed: Q21.1 (G), R39.1
unnamed: Q21.3 (D), Q27.1 (G), Q28.1 (G), R43.2
unnamed: Q22.1 (G), R40.1
unnamed: Q23.1 (G), R41.1
unnamed: Q24.1 (G), R42.1
unnamed: Q25.1 (G), R53.1
unnamed: Q4.1 (G), Q6.1 (G), Q25.3 (D), R19.2
unnamed: Q26.1 (G), R54.1
unnamed: Q5.1 (G), Q8.1 (G), Q26.3 (D), R20.2
unnamed: Q27.3 (D), Q28.3 (D), R44.2
unnamed: Q29.1 (G), R56.1
unnamed: Q29.3 (D), Q30.1 (G), R57.2
unnamed: Q31.1 (G), R59.1
unnamed: Q31.3 (D), Q32.1 (G), R60.2
Oil-Level-Sensor: Q10.3 (D); also elsewhere on the board
Oil-Pressure-Switch: Q3.3 (D); also elsewhere on the board
Outside-Temp: R55.1; also elsewhere on the board
Parking-Brake-Switch: Q15.3 (D); also elsewhere on the board
Reverse: Q22.3 (D); also elsewhere on the board
Rollover-Sensor: Q20.3 (D); also elsewhere on the board
Seat-Belt: Q23.3 (D); also elsewhere on the board
Signal-Gong: R44.1; also elsewhere on the board
Speed-Signal: Q11.3 (D); also elsewhere on the board
Washer-Fluid-Level: Q18.3 (D); also elsewhere on the board

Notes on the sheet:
X11175 Pin 3 Circuit
X11175 Pin 7 Circuit
X11175 Pin 13 Circuit
X11175 Pin 14 Circuit
X11176 Pin 6 Circuit
X11176 Pin 5 Circuit
X11176 Pin 4 Circuit
X11175 Pin 24 Circuit
X11175 Pin 23 Circuit
X11175 Pin 22 Circuit
X11175 Pin 21 Circuit
X11175 Pin 20 Circuit
X11175 Pin 19 Circuit
X11175 Pin 17 Circuit
X11175 Pin 2 Circuit
X11176 Pin 7 Circuit
X11176 Pin 12 Circuit
X11176 Pin 13 Circuit
X11176 Pin 14 Circuit
X11176 Pin 1 Circuit
X11175 Pin 26 Circuit
Should keep ambient temp @ 20 degC
X11175 Pins 5 and 6 Circuit

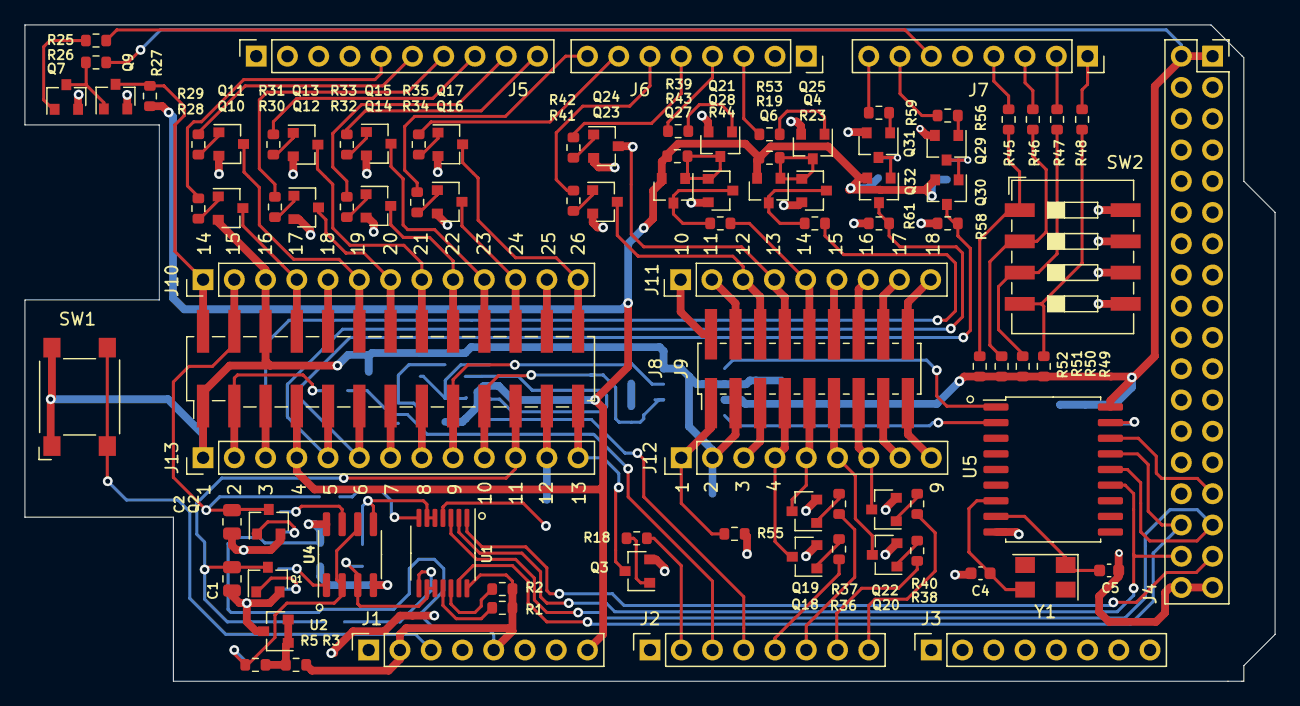
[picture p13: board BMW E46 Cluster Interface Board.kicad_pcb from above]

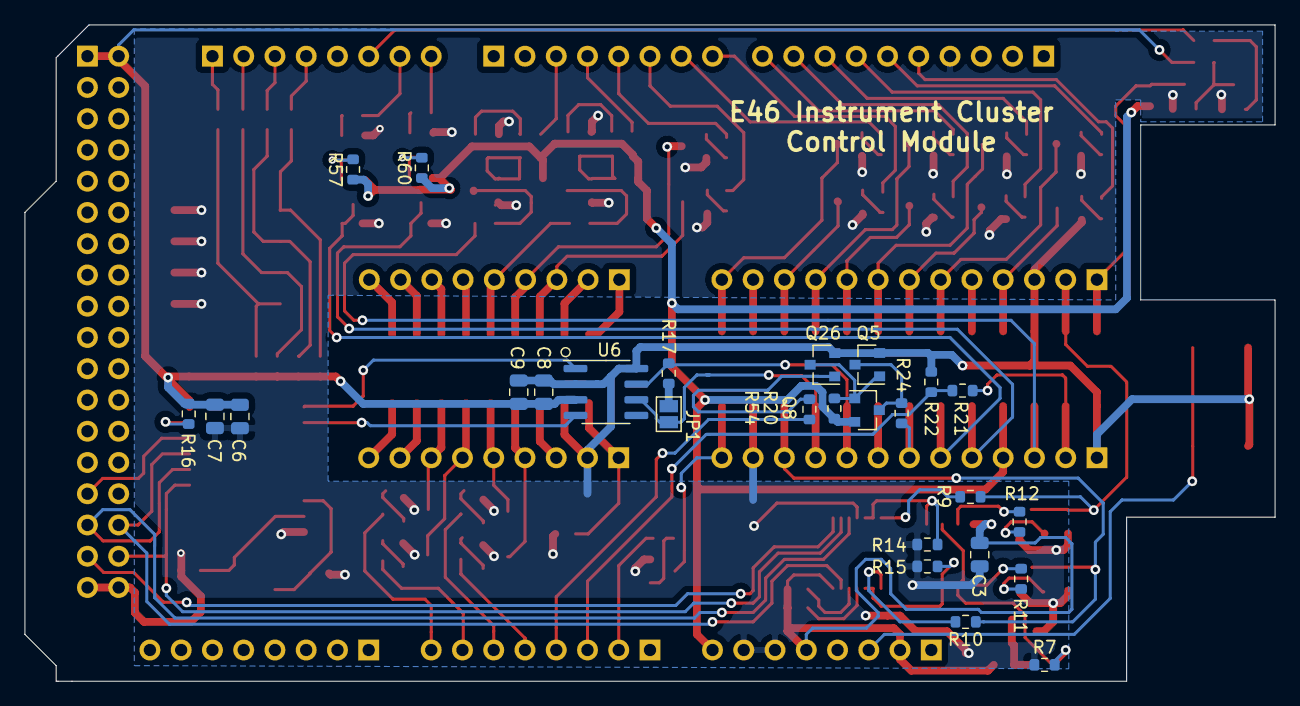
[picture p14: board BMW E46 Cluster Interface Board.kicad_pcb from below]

Board: 2 copper layers, 101.6 x 53.3 mm, 120 parts (26 on the bottom side), 126 nets.

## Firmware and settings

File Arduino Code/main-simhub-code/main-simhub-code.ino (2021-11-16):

// J revision sketch
#define VERSION 'j'

// ----------------------------------------------------- PLEASE USE SETUP ASSISTANT AVAILABLE IN SUB FOLDER !!!! -------------------------------------------
// ----------------------------------------------------- PLEASE USE SETUP ASSISTANT AVAILABLE IN SUB FOLDER !!!! -------------------------------------------
// ----------------------------------------------------- PLEASE USE SETUP ASSISTANT AVAILABLE IN SUB FOLDER !!!! -------------------------------------------
// ----------------------------------------------------- PLEASE USE SETUP ASSISTANT AVAILABLE IN SUB FOLDER !!!! -------------------------------------------
// ----------------------------------------------------- PLEASE USE SETUP ASSISTANT AVAILABLE IN SUB FOLDER !!!! -------------------------------------------
// ----------------------------------------------------- PLEASE USE SETUP ASSISTANT AVAILABLE IN SUB FOLDER !!!! -------------------------------------------
// ----------------------------------------------------- PLEASE USE SETUP ASSISTANT AVAILABLE IN SUB FOLDER !!!! -------------------------------------------
// ----------------------------------------------------- PLEASE USE SETUP ASSISTANT AVAILABLE IN SUB FOLDER !!!! -------------------------------------------
// ----------------------------------------------------- PLEASE USE SETUP ASSISTANT AVAILABLE IN SUB FOLDER !!!! -------------------------------------------
// ----------------------------------------------------- PLEASE USE SETUP ASSISTANT AVAILABLE IN SUB FOLDER !!!! -------------------------------------------
// ----------------------------------------------------- PLEASE USE SETUP ASSISTANT AVAILABLE IN SUB FOLDER !!!! -------------------------------------------
// ----------------------------------------------------- PLEASE USE SETUP ASSISTANT AVAILABLE IN SUB FOLDER !!!! -------------------------------------------

//#define INCLUDE_TM1638                      //{"Name":"INCLUDE_TM1638","Type":"autodefine","Condition":"[TM1638_ENABLEDMODULES]>0"}
//#define INCLUDE_WS2801                      //{"Name":"INCLUDE_WS2801","Type":"autodefine","Condition":"[WS2801_RGBLEDCOUNT]>0"}
//#define INCLUDE_WS2812B                     //{"Name":"INCLUDE_WS2812B","Type":"autodefine","Condition":"[WS2812B_RGBLEDCOUNT]>0"}
//#define INCLUDE_PL9823                      //{"Name":"INCLUDE_PL9823","Type":"autodefine","Condition":"[PL9823_RGBLEDCOUNT]>0"}
//#define INCLUDE_WS2812B_MATRIX              //{"Name":"INCLUDE_WS2812B_MATRIX","Type":"autodefine","Condition":"[WS2812B_MATRIX_ENABLED]>0"}
//#define INCLUDE_LEDBACKPACK                 //{"Name":"INCLUDE_LEDBACKPACK","Type":"autodefine","Condition":"[ENABLE_ADA_HT16K33_7SEGMENTS]>0 || [ENABLE_ADA_HT16K33_BiColorMatrix]>0"}
//#define INCLUDE_TM1637                      //{"Name":"INCLUDE_TM1637","Type":"autodefine","Condition":"[TM1637_ENABLEDMODULES]>0"}
//#define INCLUDE_TM1637_6D                   //{"Name":"INCLUDE_TM1637_6D","Type":"autodefine","Condition":"[TM1637_6D_ENABLEDMODULES]>0"}
//#define INCLUDE_I2CLCD                      //{"Name":"INCLUDE_I2CLCD","Type":"autodefine","Condition":"[I2CLCD_enabled]>0"}
//#define INCLUDE_NOKIALCD                    //{"Name":"INCLUDE_NOKIALCD","Type":"autodefine","Condition":"[ENABLED_NOKIALCD]>0"}
//#define INCLUDE_OLED                        //{"Name":"INCLUDE_OLED","Type":"autodefine","Condition":"[ENABLED_OLEDLCD]>0"}
//#define INCLUDE_MAX7221MATRIX               //{"Name":"INCLUDE_MAX7221MATRIX","Type":"autodefine","Condition":"[MAX7221_MATRIX_ENABLED]>0"}
//#define INCLUDE_HT16K33_SINGLECOLORMATRIX   //{"Name":"INCLUDE_HT16K33_SINGLECOLORMATRIX","Type":"autodefine","Condition":"[ENABLE_ADA_HT16K33_SingleColorMatrix]>0"}
//#define INCLUDE_74HC595_GEAR_DISPLAY        //{"Name":"INCLUDE_74HC595_GEAR_DISPLAY","Type":"autodefine","Condition":"[ENABLE_74HC595_GEAR_DISPLAY]>0"}
//#define INCLUDE_MAX7221_MODULES             //{"Name":"INCLUDE_MAX7221_MODULES","Type":"autodefine","Condition":"[MAX7221_ENABLEDMODULES]>0"}
//#define INCLUDE_6c595_GEAR_DISPLAY          //{"Name":"INCLUDE_6c595_GEAR_DISPLAY ","Type":"autodefine","Condition":"[ENABLE_6C595_GEAR_DISPLAY]>0"}
//#define INCLUDE_TACHOMETER                  //{"Name":"INCLUDE_TACHOMETER ","Type":"autodefine","Condition":"[ENABLE_TACHOMETER]>0"}
//#define INCLUDE_BOOSTGAUGE                  //{"Name":"INCLUDE_BOOSTGAUGE ","Type":"autodefine","Condition":"[ENABLE_BOOSTGAUGE]>0"}
//#define INCLUDE_SPEEDOGAUGE                 //{"Name":"INCLUDE_SPEEDOGAUGE","Type":"autodefine","Condition":"[ENABLE_SPEEDOGAUGE]>0"}
//#define INCLUDE_FUELGAUGE                   //{"Name":"INCLUDE_FUELGAUGE ","Type":"autodefine","Condition":"[ENABLE_FUELGAUGE]>0"}
//#define INCLUDE_TEMPGAUGE                   //{"Name":"INCLUDE_TEMPGAUGE ","Type":"autodefine","Condition":"[ENABLE_TEMPGAUGE]>0"}
//#define INCLUDE_CONSGAUGE                   //{"Name":"INCLUDE_CONSGAUGE ","Type":"autodefine","Condition":"[ENABLE_CONSGAUGE]>0"}
//#define INCLUDE_SHAKEITADASHIELD            //{"Name":"INCLUDE_SHAKEITADASHIELD ","Type":"autodefine","Condition":"[ADAMOTORS_SHIELDSCOUNT]>0"}
//#define INCLUDE_SHAKEITDKSHIELD             //{"Name":"INCLUDE_SHAKEITDKSHIELD ","Type":"autodefine","Condition":"[DKMOTOR_SHIELDSCOUNT]>0"}
//#define INCLUDE_SHAKEITL298N                //{"Name":"INCLUDE_SHAKEITL298N","Type":"autodefine","Condition":"[L98NMOTORS_ENABLED]>0"}
//#define INCLUDE_SHAKEITMOTOMONSTER          //{"Name":"INCLUDE_SHAKEITMOTOMONSTER","Type":"autodefine","Condition":"[MOTOMONSTER_ENABLED]>0"}
//#define INCLUDE_SHAKEIDUALVNH5019           //{"Name":"INCLUDE_SHAKEIDUALVNH5019","Type":"autodefine","Condition":"[DUALVNH5019_ENABLED]>0"}

//#define INCLUDE_SHAKEITPWM                  //{"Name":"INCLUDE_SHAKEITPWM","Type":"autodefine","Condition":"[SHAKEITPWM_ENABLED_MOTORS]>0"}
//#define INCLUDE_SHAKEITPWMFANS              //{"Name":"INCLUDE_SHAKEITPWMFANS","Type":"autodefine","Condition":"[SHAKEITPWMFANS_ENABLED_MOTORS]>0"}
#if defined (__AVR_ATmega32U4__)
//#define INCLUDE_GAMEPAD                     //{"Name":"INCLUDE_GAMEPAD","Type":"autodefine","Condition":"[ENABLE_MICRO_GAMEPAD]>0"}
#endif
//#define INCLUDE_GAMEPADAXIS                 //{"Name":"INCLUDE_GAMEPADAXIS","Type":"autodefine","Condition":"[GAMEPAD_AXIS_01_ENABLED]>0 || [GAMEPAD_AXIS_02_ENABLED]>0 || [GAMEPAD_AXIS_03_ENABLED]>0"}

#ifdef INCLUDE_GAMEPADAXIS
#ifndef  INCLUDE_GAMEPAD
#error Gamepad option must be enabled in order to use analog axis.
#endif // ! INCLUDE_GAMEPAD
#endif

//#define INCLUDE_ENCODERS                    //{"Name":"INCLUDE_ENCODERS","Type":"autodefine","Condition":"[ENABLED_ENCODERS_COUNT]>0","IsInput":true}
//#define INCLUDE_BUTTONS                     //{"Name":"INCLUDE_BUTTONS","Type":"autodefine","Condition":"[ENABLED_BUTTONS_COUNT]>0","IsInput":true}
//#define INCLUDE_BUTTONMATRIX                //{"Name":"INCLUDE_BUTTONMATRIX","Type":"autodefine","Condition":"[ENABLED_BUTTONMATRIX]>0","IsInput":true}
//#define INCLUDE_DM163_MATRIX                //{"Name":"INCLUDE_DM163_MATRIX","Type":"autodefine","Condition":"[DM163_MATRIX_ENABLED]>0"}

#include <avr/pgmspace.h>
#include <EEPROM.h>
#include <SPI.h>
#include "Arduino.h"
#include <avr/pgmspace.h>
#include <Wire.h>
#include "Adafruit_GFX.h"
#include "FlowSerialRead.h"
#include "setPwmFrequency.h"
#include "SHDebouncer.h"
#include "SHButton.h"

// ----------------------------------------------------- HW SETTINGS, PLEASE REVIEW ALL -------------------------------------------
#define DEVICE_NAME "SimHub Dash" //{"Group":"General","Name":"DEVICE_NAME","Title":"Device name,\r\n make sure to use a unique name when using multiple arduinos","DefaultValue":"SimHub Dash","Type":"string","Template":"#define DEVICE_NAME \"{0}\""}
#define DEVICE_UNIQUE_ID "b2b8aba9-134c-4c66-b2a0-cf3ac646c53b" //{"UniqueId":"b2b8aba9-134c-4c66-b2a0-cf3ac646c53b","Name":"DEVICE_UNIQUE_ID","Type":"uniqueid"}

#define ENABLE_MICRO_GAMEPAD 0           //{"Group":"GAMEPAD","Name":"ENABLE_MICRO_GAMEPAD","Title":"Enable arduino micro gamepad output for all the activated buttons/encoders","DefaultValue":"0","Type":"bool"}
#define MICRO_GAMEPAD_ENCODERPRESSTIME 50 //{"Name":"MICRO_GAMEPAD_ENCODERPRESSTIME","Title":"Define how long (in milliseconds) the encoder related button will be hold after an encoder movement","DefaultValue":"50","Type":"int","Condition":"ENABLE_MICRO_GAMEPAD>0","Max":100}

// -------------------------------------------------------------------------------------------------------
// TM1638 Modules ----------------------------------------------------------------------------------------
// http://www.dx.com/p/jy-mcu-8x-green-light-digital-tube-8x-key-8x-double-color-led-module-104329
// https://www.fasttech.com/products/0/10006503/1497600-jy-mcu-8x-digital-tube-red-led-module
// -------------------------------------------------------------------------------------------------------
// Number of Connected TM1638/1639 modules
// 0 disabled, > 0 enabled
#define TM1638_ENABLEDMODULES 0 //{"Group":"TM1638 7 Segments Modules","Name":"TM1638_ENABLEDMODULES","Title":"TM1638 modules connected","DefaultValue":"0","Type":"int","Max":6}
#ifdef INCLUDE_TM1638
#define TM1638_SWAPLEDCOLORS 0  //{"Name":"TM1638_SWAPLEDCOLORS","Title":"Reverse Red and green colors ","DefaultValue":"0","Type":"bool","Condition":"TM1638_ENABLEDMODULES > 0"}
#define TM1638_DIO 8            //{"Name":"TM1638_DIO","Title":"Common data (DIO) digital pin number","DefaultValue":"8","Type":"pin;TM1638 DIO","Condition":"TM1638_ENABLEDMODULES > 0"}
#define TM1638_CLK 7            //{"Name":"TM1638_CLK","Title":"Common clock (CLK) digital pin number","DefaultValue":"7","Type":"pin;TM1638 CLK","Condition":"TM1638_ENABLEDMODULES > 0"}
#define TM1638_STB1 9           //{"Name":"TM1638_STB1","Title":"1st module strobe (STB0) digital pin number","DefaultValue":"9","Type":"pin;TM1638 STB1","Condition":"TM1638_ENABLEDMODULES > 0"}
#define TM1638_SINGLECOLOR1 0   //{"Name":"TM1638_SINGLECOLOR1","Title":"1st module is single color","DefaultValue":"0","Type":"bool","Condition":"TM1638_ENABLEDMODULES > 0"}

#define TM1638_STB2 10          //{"Name":"TM1638_STB2","Title":"2nd module strobe (STB1) digital pin number","DefaultValue":"10","Type":"pin;TM1638 STB2","Condition":"TM1638_ENABLEDMODULES > 1"}
#define TM1638_SINGLECOLOR2 0   //{"Name":"TM1638_SINGLECOLOR2","Title":"2nd module is single color","DefaultValue":"0","Type":"bool","Condition":"TM1638_ENABLEDMODULES > 1"}

#define TM1638_STB3 11          //{"Name":"TM1638_STB3","Title":"3rd module strobe (STB2) digital pin number","DefaultValue":"11","Type":"pin;TM1638 STB3","Condition":"TM1638_ENABLEDMODULES > 2"}
#define TM1638_SINGLECOLOR3 0   //{"Name":"TM1638_SINGLECOLOR3","Title":"3rd module is single color","DefaultValue":"0","Type":"bool","Condition":"TM1638_ENABLEDMODULES > 2"}

#define TM1638_STB4 12          //{"Name":"TM1638_STB4","Title":"4th module strobe (STB3) digital pin number","DefaultValue":"12","Type":"pin;TM1638 STB4","Condition":"TM1638_ENABLEDMODULES > 3"}
#define TM1638_SINGLECOLOR4 0   //{"Name":"TM1638_SINGLECOLOR4","Title":"4th module is single color","DefaultValue":"0","Type":"bool","Condition":"TM1638_ENABLEDMODULES > 3"}

#define TM1638_STB5 0           //{"Name":"TM1638_STB5","Title":"5th module strobe (STB4) digital pin number","DefaultValue":"0","Type":"pin;TM1638 STB5","Condition":"TM1638_ENABLEDMODULES > 4"}
#define TM1638_SINGLECOLOR5 0   //{"Name":"TM1638_SINGLECOLOR5","Title":"5th module is single color","DefaultValue":"0","Type":"bool","Condition":"TM1638_ENABLEDMODULES > 4"}

#define TM1638_STB6 0           //{"Name":"TM1638_STB6","Title":"6th module strobe (STB5) digital pin number","DefaultValue":"0","Type":"pin;TM1638 STB6","Condition":"TM1638_ENABLEDMODULES > 5"}
#define TM1638_SINGLECOLOR6 0   //{"Name":"TM1638_SINGLECOLOR6","Title":"6th module is single color","DefaultValue":"0","Type":"bool","Condition":"TM1638_ENABLEDMODULES > 5"}

#include "SHTM1638.h"
#endif

// -------------------------------------------------------------------------------------------------------
// TM1637 Modules ----------------------------------------------------------------------------------------
// http://www.dx.com/p/0-36-led-4-digit-display-module-for-arduino-black-blue-works-with-official-arduino-boards-254978
// -------------------------------------------------------------------------------------------------------
// Number of Connected TM1637 modules
// 0 disabled, > 0 enabled
#define TM1637_ENABLEDMODULES 0 //{"Group":"TM1637 7 Segment Modules","Name":"TM1637_ENABLEDMODULES","Title":"TM1637 modules connected","DefaultValue":"0","Type":"int","Max":8}
#ifdef INCLUDE_TM1637

#define TM1637_DIO1 4           //{"Name":"TM1637_DIO1","Title":"1st TM1637 DIO digital pin number","DefaultValue":"4","Type":"pin;TM1637 #1 DIO","Condition":"TM1637_ENABLEDMODULES >=1"}
#define TM1637_CLK1 3           //{"Name":"TM1637_CLK1","Title":"1st TM1637 CLK digital pin number","DefaultValue":"3","Type":"pin;TM1637 #1 CLK","Condition":"TM1637_ENABLEDMODULES >=1"}
#define TM1637_DIO2 4           //{"Name":"TM1637_DIO2","Title":"2nd TM1637 DIO digital pin number","DefaultValue":"4","Type":"pin;TM1637 #2 DIO","Condition":"TM1637_ENABLEDMODULES >=2"}
#define TM1637_CLK2 3           //{"Name":"TM1637_CLK2","Title":"2nd TM1637 CLK digital pin number","DefaultValue":"3","Type":"pin;TM1637 #2 CLK","Condition":"TM1637_ENABLEDMODULES >=2"}
#define TM1637_DIO3 4           //{"Name":"TM1637_DIO3","Title":"3rd TM1637 DIO digital pin number","DefaultValue":"4","Type":"pin;TM1637 #3 DIO","Condition":"TM1637_ENABLEDMODULES >=3"}
#define TM1637_CLK3 3           //{"Name":"TM1637_CLK3","Title":"3rd TM1637 CLK digital pin number","DefaultValue":"3","Type":"pin;TM1637 #3 CLK","Condition":"TM1637_ENABLEDMODULES >=3"}
#define TM1637_DIO4 4           //{"Name":"TM1637_DIO4","Title":"4th TM1637 DIO digital pin number","DefaultValue":"4","Type":"pin;TM1637 #4 DIO","Condition":"TM1637_ENABLEDMODULES >=4"}
#define TM1637_CLK4 3           //{"Name":"TM1637_CLK4","Title":"4th TM1637 CLK digital pin number","DefaultValue":"3","Type":"pin;TM1637 #4 CLK","Condition":"TM1637_ENABLEDMODULES >=4"}
#define TM1637_DIO5 4           //{"Name":"TM1637_DIO5","Title":"5th TM1637 DIO digital pin number","DefaultValue":"4","Type":"pin;TM1637 #5 DIO","Condition":"TM1637_ENABLEDMODULES >=5"}
#define TM1637_CLK5 3           //{"Name":"TM1637_CLK5","Title":"5th TM1637 CLK digital pin number","DefaultValue":"3","Type":"pin;TM1637 #5 CLK","Condition":"TM1637_ENABLEDMODULES >=5"}
#define TM1637_DIO6 4           //{"Name":"TM1637_DIO6","Title":"6th TM1637 DIO digital pin number","DefaultValue":"4","Type":"pin;TM1637 #6 DIO","Condition":"TM1637_ENABLEDMODULES >=6"}
#define TM1637_CLK6 3           //{"Name":"TM1637_CLK6","Title":"6th TM1637 CLK digital pin number","DefaultValue":"3","Type":"pin;TM1637 #6 CLK","Condition":"TM1637_ENABLEDMODULES >=6"}
#define TM1637_DIO7 4           //{"Name":"TM1637_DIO7","Title":"7th TM1637 DIO digital pin number","DefaultValue":"4","Type":"pin;TM1637 #7 DIO","Condition":"TM1637_ENABLEDMODULES >=7"}
#define TM1637_CLK7 3           //{"Name":"TM1637_CLK7","Title":"7th TM1637 CLK digital pin number","DefaultValue":"3","Type":"pin;TM1637 #7 CLK","Condition":"TM1637_ENABLEDMODULES >=7"}
#define TM1637_DIO8 4           //{"Name":"TM1637_DIO8","Title":"8th TM1637 DIO digital pin number","DefaultValue":"4","Type":"pin;TM1637 #8 DIO","Condition":"TM1637_ENABLEDMODULES >=8"}
#define TM1637_CLK8 3           //{"Name":"TM1637_CLK8","Title":"8th TM1637 CLK digital pin number","DefaultValue":"3","Type":"pin;TM1637 #8 CLK","Condition":"TM1637_ENABLEDMODULES >=8"}

#include "SHTM1637.h"

#endif

// -------------------------------------------------------------------------------------------------------
// TM1637 6 DIGITS Modules ----------------------------------------------------------------------------------------
// http://www.dx.com/p/0-36-led-4-digit-display-module-for-arduino-black-blue-works-with-official-arduino-boards-254978
// -------------------------------------------------------------------------------------------------------
// Number of Connected TM1637 modules
// 0 disabled, > 0 enabled
#define TM1637_6D_ENABLEDMODULES 0 //{"Group":"TM1637 6Digits 7 Segment Modules","Name":"TM1637_6D_ENABLEDMODULES","Title":"TM1637 modules connected","DefaultValue":"0","Type":"int","Max":8}
#ifdef INCLUDE_TM1637_6D
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
void loop() {
#ifdef INCLUDE_SHAKEITL298N
	shShakeitL298N.safetyCheck();
#endif
#ifdef INCLUDE_SHAKEITMOTOMONSTER
	shShakeitMotoMonster.safetyCheck();
#endif
#ifdef INCLUDE_SHAKEIDUALVNH5019
	shShakeitDualVNH5019.safetyCheck();
#endif
#ifdef INCLUDE_SHAKEITADASHIELD
	shShakeitAdaMotorShieldV2.safetyCheck();
#endif
#ifdef INCLUDE_SHAKEITDKSHIELD
	shShakeitDKMotorShield.safetyCheck();
#endif
#ifdef INCLUDE_SHAKEITPWM
	shShakeitPWM.safetyCheck();
#endif
#ifdef INCLUDE_SHAKEITPWMFANS
	shShakeitPWMFans.safetyCheck();
#endif
#ifdef INCLUDE_GAMEPAD
	UpdateGamepadState();
#endif

	shCustomProtocol.loop();

	// Wait for data
	if (FlowSerialAvailable() > 0) {
		if (FlowSerialTimedRead() == MESSAGE_HEADER)
		{
			lastSerialActivity = millis();
			// Read command
			loop_opt = FlowSerialTimedRead();

			if (loop_opt == '1') Command_Hello();
			else if (loop_opt == '8') Command_SetBaudrate();
			else if (loop_opt == 'J') Command_ButtonsCount();
			else if (loop_opt == '2') Command_TM1638Count();
			else if (loop_opt == 'B') Command_SimpleModulesCount();
			else if (loop_opt == 'A') Command_Acq();
			else if (loop_opt == 'N') Command_DeviceName();
			else if (loop_opt == 'I') Command_UniqueId();
			else if (loop_opt == '0') Command_Features();
			else if (loop_opt == '3') Command_TM1638Data();
			else if (loop_opt == 'V') Command_Motors();
			else if (loop_opt == 'S') Command_7SegmentsData();
			else if (loop_opt == '4') Command_RGBLEDSCount();
			else if (loop_opt == '6') Command_RGBLEDSData();
			else if (loop_opt == 'R') Command_RGBMatrixData();
			else if (loop_opt == 'M') Command_MatrixData();
			else if (loop_opt == 'G') Command_GearData();
			else if (loop_opt == 'L') Command_I2CLCDData();
			else if (loop_opt == 'K') Command_GLCDData(); // Nokia | OLEDS
			else if (loop_opt == 'P') Command_CustomProtocolData();
			else if (loop_opt == 'X')
			{
				String xaction = FlowSerialReadStringUntil(' ', '\n');
				if (xaction == F("list")) Command_ExpandedCommandsList();
				else if (xaction == F("mcutype")) Command_MCUType();
				else if (xaction == F("tach")) Command_TachData();
				else if (xaction == F("speedo")) Command_SpeedoData();
				else if (xaction == F("boost")) Command_BoostData();
				else if (xaction == F("temp")) Command_TempData();
				else if (xaction == F("fuel")) Command_FuelData();
				else if (xaction == F("cons")) Command_ConsData();
				else if (xaction == F("encoderscount")) Command_EncodersCount();
			}
		}
	}

	if (millis() - lastSerialActivity > 5000) {
		Command_Shutdown();
	}
}

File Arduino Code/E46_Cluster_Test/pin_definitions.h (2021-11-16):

// Outputs
#define ENGINE_START_FEEDBACK_PIN 2
#define SIGNAL_GONG_PIN 3
#define BC_BUTTON_PIN 4
#define SEAT_BELT_PIN 5
#define COOLANT_LEVEL_SENSOR_PIN 6
#define BRAKE_WEAR_SENSOR_PIN 7
#define PARKING_BRAKE_PIN 8
#define ABS_WARNING_PIN 9
#define AIRBAG_WARNING_PIN 10
#define BRAKE_FLUID_PIN 11
#define SPEED_SIGNAL_PIN 12
#define OIL_LEVEL_SENSOR_PIN 13
#define IGNITION_ON_PIN 14
#define ACCESSORY_MODE_PIN 15
#define KBUS Serial2
#define OIL_PRESSURE_SWITCH_PIN A1
#define BATTERY_CHARGE_INDICATOR_PIN A2
#define CLUSTER_BACKLIGHT_PIN A3
#define WASHER_FLUID_LEVEL_PIN A4
#define CRUISE_CONTROL_LIGHT_PIN A5
#define ROLLOVER_SENSOR_PIN A6
#define REVERSE_PIN A7

// DIP Switches
#define DIP_SWITCH_1 18
#define DIP_SWITCH_2 19
#define DIP_SWITCH_3 20
#define DIP_SWITCH_4 21

// SPI Pins
#define MCP2515_CS 49
#define MISO_PIN 50
#define MOSI_PIN 51
#define SCK_PIN 52
#define DIGI_POT_CS 53

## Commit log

2021-11-16 First upload of all codes / hardware files for this project
    [Arduino_Connectors.sch, BMW E46 Cluster Interface Board.kicad_pcb, BMW E46 Cluster Interface Board.sch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]
2021-11-16 Updated docstrings in Arduino code
2021-11-23 Updated the default configuration for the washer fluid circuit after testing
